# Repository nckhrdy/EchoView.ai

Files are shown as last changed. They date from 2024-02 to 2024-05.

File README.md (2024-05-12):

# EchoView.ai: AR Glasses for the Deaf and Hard of Hearing

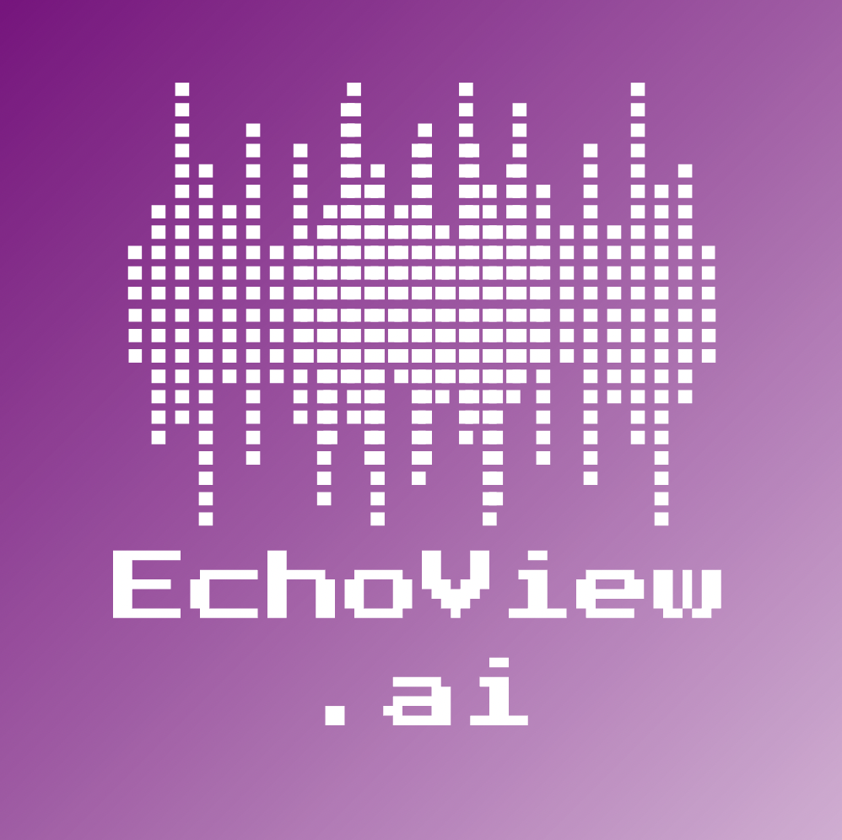
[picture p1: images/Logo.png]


## Introduction
EchoView.ai introduces an innovative solution designed to significantly enhance communication for the Deaf and Hard of Hearing community. Utilizing advanced technology, our glasses provide real-time speech-to-text transcription, displaying conversations directly in the user's field of vision.

## Mission Statement
Our mission is to foster community and innovation by enabling everyone to hold the key to understanding spoken interactions.

## Key Features
- **Real-Time Transcription:** Speech-to-text functionality that operates in real-time.
- **OLED Display:** Text is displayed on a discreet, built-in OLED screen within the glasses.
- **Bluetooth Connectivity:** Seamless integration with iOS devices through a custom app.
- **User-Friendly Design:** Lightweight, comfortable, and designed for everyday wear.

## System Overview
EchoView.ai glasses are powered by an ESP32-C3, featuring audio capturing and an OLED display for output. The system includes:
- ESP32-C3 for processing
- JVC HA-ET65BV Microphone and Device microphone, also compatible with MEMS microphones and various other audio inputs
- OLED display for text output
- Bluetooth module for mobile connectivity
- Birdbath Combiners/Optical Combiner (series of two-way mirrors) for projecting the image from OLED

## Installation
### Hardware Setup (Detailed information in README_hardware.md)
1. Connect the MEMS microphones to the ESP32-C3.
2. Attach the OLED display to the ESP32-C3.
3. Ensure all connections are secure and the system is powered (3.3v).

### Software Setup (Detailed information in README_software.md)
1. Clone this repository to your ESP32-C3.
2. Navigate to the /Device directory and flash the echoview_esp32_v1.ino file onto the ESP32.

## Usage
### Starting the Device
Power on the EchoView.ai glasses. The device will automatically boot up and the Raspberry Pi will begin processing input from the microphones.

### Using the Mobile App
1. Download the EchoView.ai app from the iOS App Store.
2. Press and hold the button on the side of the headset for 3 seconds until device flashes 3 times.
3. Navigate to Bluetooth in device Settings and connect to the headset.
4. Open the app and pair it with your EchoView.ai glasses.
5. Start Transcribing!

### Daily Operation
Simply wear the glasses as you would any regular glasses. Conversations will be transcribed in real-time and displayed in your field of view.

## Safety and Maintenance
- Keep the device dry and avoid exposure to extreme temperatures.
- Regularly update the software through the EchoView.ai app to ensure optimal performance and security.

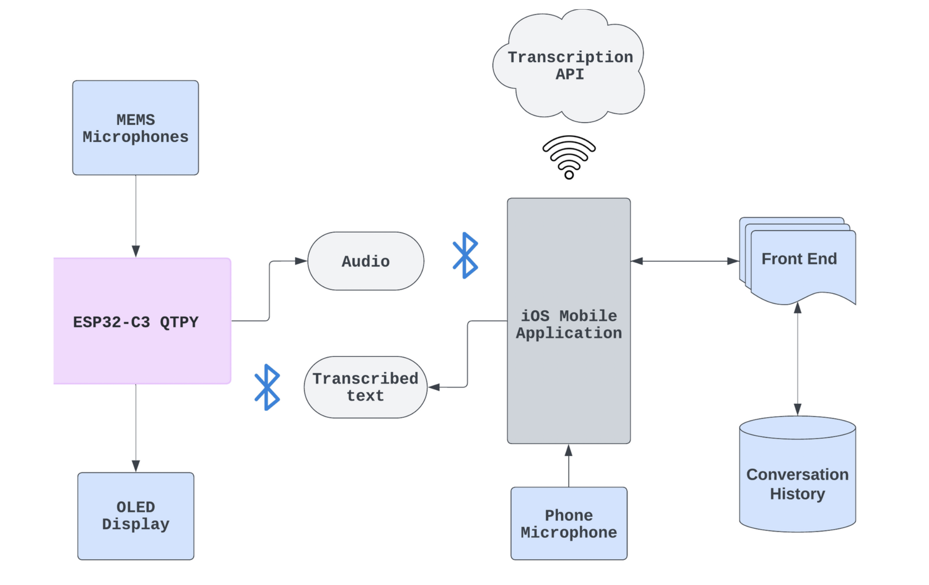
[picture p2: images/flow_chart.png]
Flow Chart


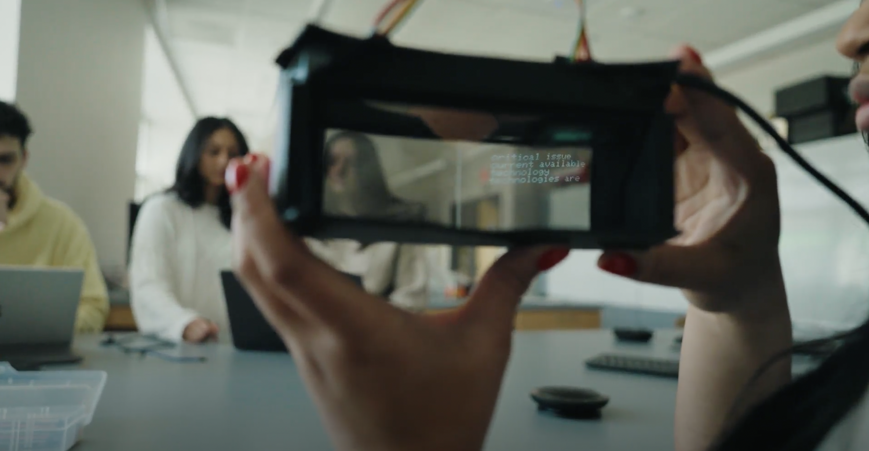
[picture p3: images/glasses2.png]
Watch the Demo (https://drive.google.com/file/d/1j2KLc6h1_2RdIPNPQ-ITHF-1azErev8u/view?usp=sharing "Watch the Demo")


For more detailed information, please refer to our [User Manual](Documentation/CopyOfPreviousReports/UserManual.pdf)

## Future Plans
EchoView.ai is exploring the integration of large language models from Hugging Face to enhance the device's capabilities. This will enable compatibility with Android devices and introduce additional languages and smart features, improving accessibility and user experience.

## Acknowledgments
Special thanks to our team members and advisors who have made significant contributions to the development and success of this project.

---
EchoView.ai – Bridging the communication gap with cutting-edge technology.

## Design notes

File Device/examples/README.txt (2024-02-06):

This bundle contains two folders, one each for the latest versions of CircuitPython. You must use the files that match the version of CircuitPython you're using, e.g. if you are using CircuitPython 7, you will copy the files from the CircuitPython 7.x folder to your CIRCUITPY drive.
To use this project bundle, simply copy the contents of the CircuitPython version folder you're using from the zip file to your CIRCUITPY drive.
Contents in each version include:
* the code.py file
* the lib/ folder and all of its contents (including subfolders and .mpy or .py files)
* any assets (such as images, sounds, etc.)
NOTE: This will replace the current code.py, and the lib folder and its contents. Back up any desired code before copying these files!
 This zip was downloaded from https://learn.adafruit.com/monochrome-oled-breakouts/python-usage-2 on February  6, 2024.

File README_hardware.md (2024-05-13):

# EchoView.ai: Hardware Report

## Overview

Our EchoView.ai device is a wearable technology enabling real-time speech-to-text transcription. This hardware report provides detailed insights into the components, schematics, and assembly required to bring EchoView.ai to life.

## Schematic and CAD Diagrams

- **System Schematic**:
<div align="center">
  
</div>

- **CAD Diagrams**:  
  - The CAD diagrams detail the physical configuration of the system's key modules.
<div align="center">
  
  <br>
  
</div>

## Bill of Materials (BOM)

### Main Components

1. **ESP32 Huzzah Feather**  
   - *Vendor*: Adafruit  
   - *Description*: An ESP32-based microcontroller board with Wi-Fi connectivity.  
   - *Link*: [ESP32 Huzzah Feather](https://www.adafruit.com/product/3405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)

2. **JVC HA-ET65BV Microphone**  
   - *Vendor*: JVC  
   - *Description*: Bluetooth-enabled, wireless sports headset with in-line microphone.
   - *Link*: [JVC Bluetooth Headset](https://www.amazon.com/JVC-Bluetooth-Headset-Wireless-Compatible/dp/B07YT8MZK4)

3. **OLED Display**  
   - *Vendor*: Adafruit  
   - *Description*: 1.3" monochrome OLED display.
   - *Link*: [Monochrome 1.3" OLED Graphic Display](https://www.electromaker.io/shop/product/monochrome-13-oled-graphic-display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)
  
4. **Lenovo Mirage Headset (Optical Combiner & Head Strap)**  
   - *Vendor*: Lenovo  
   - *Description*: Virtual reality headset used for its optical combiner and head strap.  
   - *Link*: [Lenovo Mirage Star Wars Headset](https://www.amazon.com/Star-Wars-Challenges-Lightsaber-Controller-Tracking/dp/B075C9NT67)

### Full Bill of Materials (BOM)

For a complete list of all components, including part numbers and sources, see the [BOM PDF].

## Power Requirements

- **Input Voltage**: 5V  
- **Current**: Up to 2A  
- **Power Supply Model**: Miady 5000mAh Portable Charger  
- *Link*: [Miady 5000mAh Battery Pack](https://www.amazon.com/Miady-5000mAh-Portable-Charger-Android/dp/B08T8TDS8S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)

## System Enclosure

**Material**: Grey PLA Filament  
  - *Vendor*: HATCHBOX  
  - *Description*: Durable, easy-to-print PLA filament for 3D printers, 1kg spool.  
  - *Link*: [HATCHBOX Grey PLA Filament](https://www.amazon.com/HATCHBOX-3D-Filament-Dimensional-Accuracy/dp/B015I1CYFE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)

**Lenovo Mirage Headset Components**  
  - **Optical Combiner**: Extracted from the Lenovo Mirage headset to provide optical clarity.  
  - **Head Strap**: The adjustable head strap from the Lenovo Mirage headset ensures a secure fit.  
  - *Link*: [Lenovo Mirage Star Wars Headset](https://www.amazon.com/Star-Wars-Challenges-Lightsaber-Controller-Tracking/dp/B075C9NT67)

### System Pictures

- **Angle 1**: *Insert photo here*  
- **Angle 2**: *Insert photo here*

## References and Documentation

- **Datasheets**  
  - **ESP32 Huzzah Feather**: [Datasheet PDF](https://cdn-learn.adafruit.com/downloads/pdf/adafruit-huzzah32-esp32-feather.pdf)  
  - **JVC HA-C300 Bluetooth Headset Microphone**: [Product Details at JVC](https://www.jvc.com/usa/headphones/wireless-earbuds/ha-c300/)  
  - **Monochrome 1.3" OLED Graphic Display**: [Datasheet PDF](https://www.electromaker.io/shop/download/monochrome-13-oled-graphic-display)
  - **Lenovo Mirage Headset**: [Product Overview and Specifications](https://smartsupport.lenovo.com/us/en/products/smart/arvr/jedi-challenges/solutions/pd500106-star-wars-jedi-challenges-overview)
 
- **Web Resources**  
  - **Optical Combiner**: [AltexSoft Blog](https://www.altexsoft.com/blog/augmented-reality-check-get-ready-to-ditch-your-smartphone-for-goggles/)

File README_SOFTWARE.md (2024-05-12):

# README_SOFTWARE.md

## Overview

EchoView.AI is designed to enhance communication accessibility for the deaf and hard-of-hearing community through real-time speech-to-text transcription. This comprehensive software documentation covers both the iOS application and the embedded software on the ESP32-C3, providing detailed setup, dependencies, and operational guidelines necessary for deployment and development.
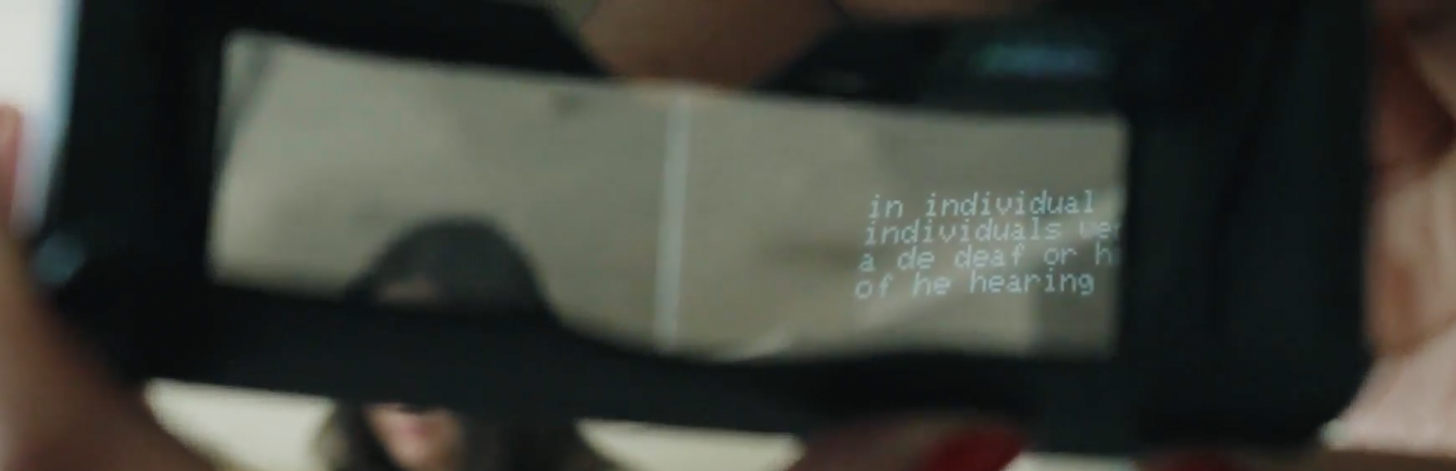
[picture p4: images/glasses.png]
Glasses


## Software Modules Overview
### **iOS Swift Application**

#### Overview
The iOS Swift application serves as the user interface for the EchoView.AI system, providing real-time speech transcription, Bluetooth management, and user settings customization. Developed using SwiftUI and Swift 5, the app leverages advanced iOS frameworks like CoreBluetooth for BLE communications and CoreData for data persistence.

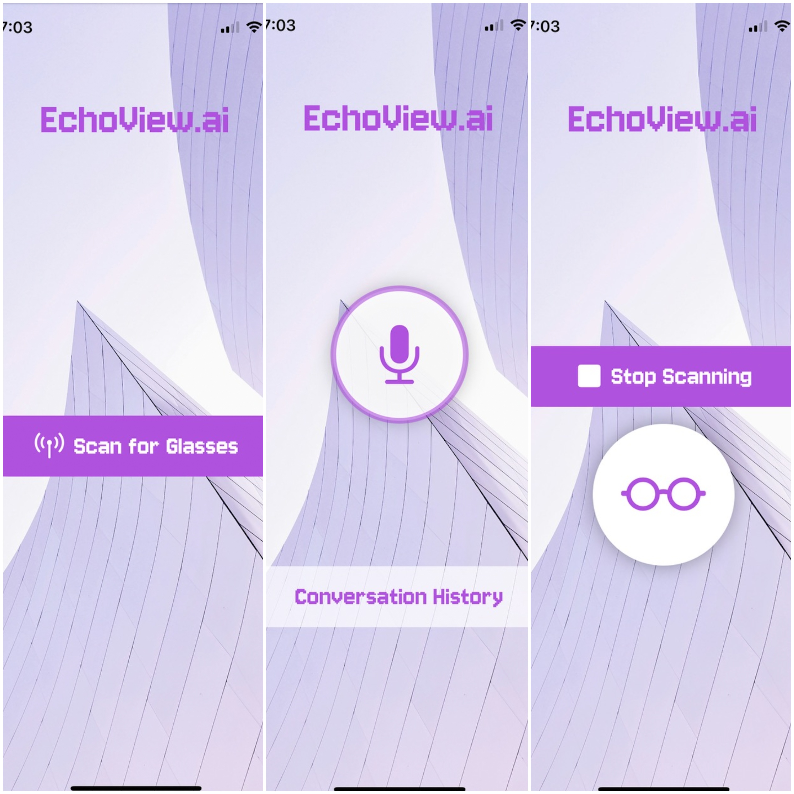
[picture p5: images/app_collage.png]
Swift App


#### Key Components
- ContentView.swift: The root view of the application, managing the main user interface elements and interactions.
- BluetoothManager.swift: Manages all Bluetooth-related operations, including scanning for devices, connecting, and data transmission.
- SpeechRecognizer.swift: Utilizes the iOS Speech framework to convert spoken language into text, managing both the audio session and speech recognition tasks.
- PersistenceController.swift: Handles all data persistence operations using CoreData, saving and retrieving transcription records.
- TranscriptionDetail.swift: Defines the data model for a transcription record, including attributes for storing date, text, and associated metadata.

#### Features
- Language/Frameworks: Developed in Swift 5 and SwiftUI for a native iOS experience.
- Main Features:
  - Bluetooth Low Energy (BLE): Manages communication with the ESP32-C3 microcontroller.
  - Transcription Display: Shows real-time transcriptions and manages transcription history.
  - Settings Customization: Allows users to customize text display settings such as size and color.

#### Operational Flow for iOS Swift Application
- Initialization:
  - Set up the main user interface.
  - Initialize core data stack for persistence.
  - Configure Bluetooth manager.
- Bluetooth Operations:
  - Scan for available BLE devices.
  - Connect to the ESP32 device.
  - Handle BLE state changes and errors.
- Transcription Management:
  - Start transcription service when user initiates.
  - Process incoming audio and convert it to text.
  - Display real-time transcription on the UI.
- Data Handling:
  - Store transcriptions in CoreData for historical access.
  - Allow users to review and manage past transcriptions.
- User Interaction:
  - Provide settings for users to customize text appearance.
  - Handle user inputs for starting/stopping transcription.
  - Navigate through different views via the navigation stack.
- Background Operations:
  - Manage app state changes (background to foreground).
  - Maintain active BLE connections and data transfer.
- Termination:
  - Properly disconnect from BLE device.
  - Save all unsaved data before app closes.
  - Clean up resources to prevent memory leaks.
---
### Embedded Software on ESP32-C3

#### Features
- Language/Platform: Implemented in C++ using the Arduino development environment.
- Main Features:
  - BLE Communication Handling: Manages BLE operations including device pairing and data transmission.
  - Audio Input Management: Captures and processes audio input from MEMS microphones.
  - Data Processing: Converts audio signals into formatted text to be sent back to the iOS application.

#### Overview
The firmware for the ESP32 microcontroller manages the Bluetooth Low Energy (BLE) communications and the OLED display to show text received from the iOS application. It is developed using the Arduino platform and utilizes the Adafruit_GFX and Adafruit_SSD1306 libraries for display operations and the BLEDevice library for BLE functionality.

#### Key Components
- echoview_esp32_v1.ino: This is the main file of the ESP32 firmware. It includes the setup and loop functions where the BLE server is configured, and the OLED display is managed.

#### Details
- BLE Setup: The firmware initializes a BLE server, advertises services, and handles connections and disconnections. It defines custom service and characteristic UUIDs to facilitate communication with the iOS application.
- OLED Display Management: Using the Adafruit_SSD1306 library, the firmware controls an OLED display to show text messages received over BLE. The text display supports basic scrolling when messages exceed the display area.
- Data Handling: Implements a callback mechanism to receive and process text data sent from the connected BLE device. The text is then displayed on the OLED screen and optionally echoed back to confirm receipt.

#### Functions
- addText(String text): Adds text to the display, managing line breaks and scrolling.
- MyServerCallbacks: Handles events for BLE server connections and disconnections.
- MyCallbacks: Processes write operations on the BLE characteristic, updating the display with received text.

#### Operational Flow
- Initialization:
  - Start Serial communication.
  - Initialize BLE server and services.
  - Set up OLED display.
- BLE Operations:
  - Advertise BLE service and characteristics.
  - Handle BLE connections and disconnections.
  - React to data written to input characteristics.
- Display Management:
  - Receive text via BLE.
  - Check if new text exceeds the display area.
  - Scroll display if necessary or append new text.
  - Update OLED display to show new text.
- Continuous Operation:
  - Maintain BLE availability.
  - Keep listening for incoming BLE connections and data.
  - Refresh OLED display based on received data.
- Handling Disconnections:
  - Automatically restart advertising to allow reconnection.
  - Clear display or display a status message.
---
### **OLED Display Management**

#### Overview
The OLED display management is implemented using a Python script running on a device equipped with an I2C interface, such as an ESP32 or Raspberry Pi. This script uses the Adafruit_SSD1306 library to control an OLED display and display text data dynamically. It is designed to handle streaming output from a subprocess, which can be customized for various use cases such as displaying real-time speech to text transcriptions.

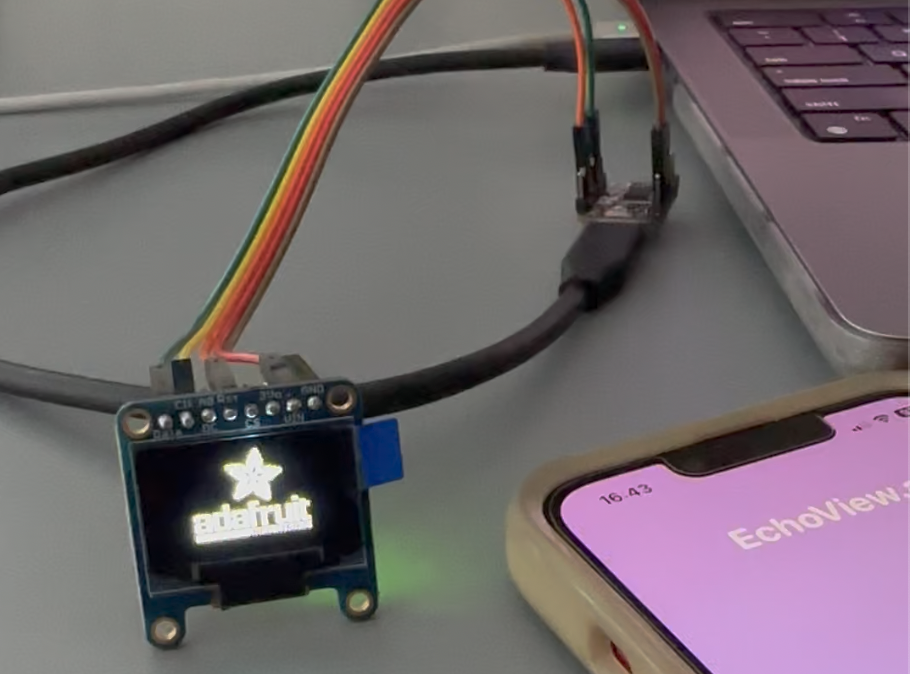
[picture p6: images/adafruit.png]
Adafruit

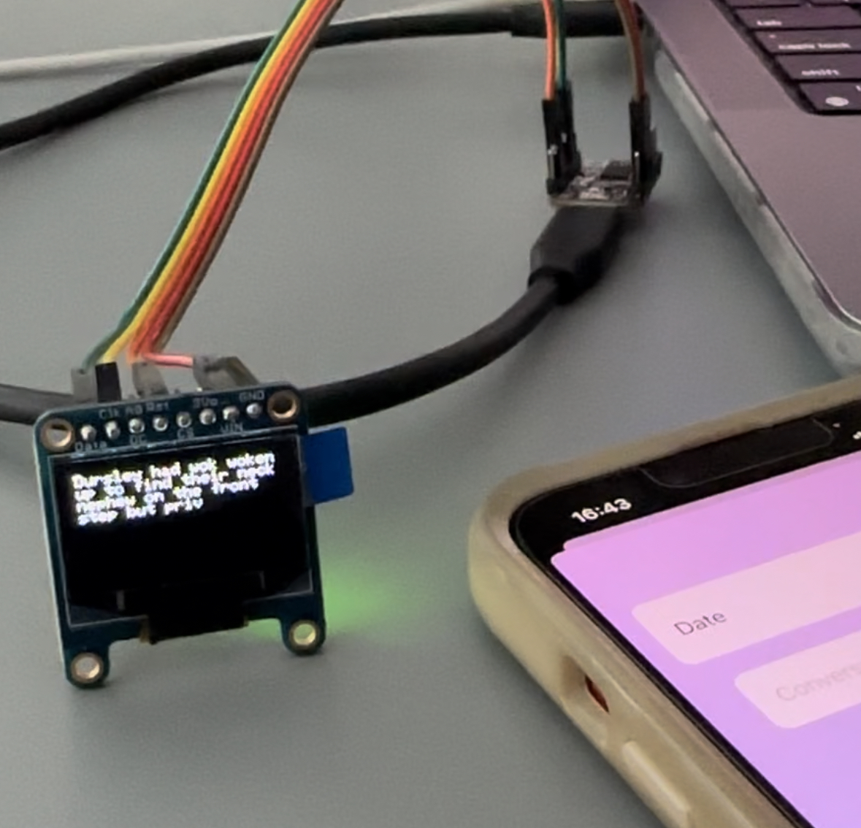
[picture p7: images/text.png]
Text


#### Key Components
- echoviewai_v.0.1.py: The main Python script that initializes the OLED display, processes incoming text, and updates the display in real-time.

#### Details
- Initialization: Sets up the I2C interface and initializes the OLED display using specific dimensions and address.
- Text Display Management: Uses the Python Imaging Library (PIL) to create an image buffer where text is drawn. The script wraps text to fit the OLED display's width and updates the display with new text as it arrives.
- Subprocess Management: Starts a subprocess that is intended to continuously provide output text, which is read line by line and displayed on the OLED.

#### Functions
- update_display(text): A function that clears the current display, wraps the incoming text based on the display's width, and updates the OLED screen to show the new text.

#### Operational Flow
The following flow chart illustrates the operational logic from subprocess initiation to display updating:
- Initialization:
  - Initialize I2C interface.
  - Set up OLED display with Adafruit_SSD1306.
- Script Execution:
  - Start a subprocess to stream output.
- Display Update Process:
  - Read output from the subprocess line by line.
  - Clear display.
  - Wrap text to fit display width.
  - Update display with new text.
- Continual Update:
  - Loop through the subprocess output.
  - Handle each line of text in real-time.
  - Refresh the OLED display with each new line.
- End Process:
  - Close subprocess.
  - Clear display on script termination.

## Flow Chart
The following flow chart illustrates the interaction between the iOS application, the ESP32-C3 microcontroller, and the OLED Display:

System Interaction Flow Chart

## Dependencies and Build Tools

### iOS Application
- **Xcode 12 or later**: Essential for iOS app development.
- **Swift 5**: Programming language.
- **CocoaPods**: Dependency manager used to install and manage third-party libraries.
  - **CocoaPods Libraries**: List specific libraries and versions.
  
### ESP32-C3 Software
- **Arduino IDE**: Used for developing and uploading C++ code to the ESP32.
- **ESP32 Board Definitions**: Must be added to the Arduino IDE for ESP32 support.
- **Adafruit SSD1306 Library**: For OLED display operations.
- **Additional Libraries**: Specify other libraries and their versions.

## Setup and Installation Instructions

### iOS Application Setup
1. **Clone the repository:**
   ```bash
   git clone https://github.com/nckhrdy/EchoView.ai.git
   ```
2. **Install dependencies:**
   ```bash
   cd EchoView.ai/App/ios
   pod install
   ```
3. **Open the .xcworkspace file in Xcode:**
   ```bash
   cd EchoView.ai.xcworkspace
   cd project.xcworkspace
   ```
4. **Build and run the application on a compatible iOS device.**

### ESP32-C3 Firmware Setup
1. **Install the Arduino IDE and ESP32 Board definitions.**
2. **Go into Folder where the firmware / ESP32 software is located:**
   ```bash
   cd Device
   ```
3. **Open the file (echoview_esp32_v1.ino) in Arduino IDE**
4. **Connect the ESP32-C3 via USB and select the correct port in Arduino IDE.**
5. **Compile and upload the software to the ESP32-C3**

## Build and Deployment

### iOS Application
- Use Xcode to build and deploy the application on an iOS device
- Ensure the device's Bluetooth is turned on and pair it with ESP32-C3

### ESP32-C3
- The ESP32-C3 auto-starts the software upon boot
- Make sure it is powered and in range of the iOS device for initial BLE pairing
- Compile the firmware in the Arduino IDE.
- Use the 'Upload' button to flash the compiled binary directly to the connected ESP32 device

## Hardware and Software Interface

### Bluetooth Interface
- Manages connectivity between the iOS device and ESP32-C3

### Audio Data Management
- Real-time audio data capture and processing on ESP32-C3

## Future Developments

### Cross-Platform Compatibility and Language Support

As EchoView.AI evolves, we plan to enhance its accessibility and functionality by leveraging Hugging Face's Large Language Models (LLMs). These advancements are aimed at making the application compatible across both Android and iOS platforms, thereby reaching a broader user base. By integrating LLMs, we expect to introduce a variety of smart features, including:

- **Multilingual Support**: Expanding the application's language capabilities to include multiple languages, which will allow users from different linguistic backgrounds to benefit from our service.
- **Enhanced Contextual Understanding**: Utilizing the advanced natural language processing (NLP) capabilities of LLMs to improve the transcription accuracy and context awareness of the speech-to-text engine.
- **Smart Interaction Features**: Developing features that enable more interactive and responsive communication aids, such as real-time suggestions and automated responses based on the context of the conversation.

### Integration Goals

- **Android Compatibility**: Adapt the existing iOS-based application to also function seamlessly on Android devices, ensuring a uniform user experience across different mobile platforms.
- **User Interface Adaptation**: Redesign the user interface to accommodate additional features while maintaining ease of use and accessibility.

These future developments are intended to not only extend the reach of EchoView.AI but also to enhance the overall user experience by incorporating cutting-edge AI technologies. Our goal is to create a universally accessible tool that aids communication for the deaf and hard-of-hearing community in a variety of scenarios and languages.

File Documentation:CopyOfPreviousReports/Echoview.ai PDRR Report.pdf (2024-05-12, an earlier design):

EC463 – 2023 PDRR REPORT | 1

# EchoView.ai: Augmented Reality Glasses with Real-Time Speech-to-Text Capability

Hassan Hijazi, Riya Deokar, Nicholas Hardy, Jazmyn Walker, Marybel Boujaoude

Abstract— The development of Augmented Reality glasses equipped with real-time transcription capabilities will introduce groundbreaking innovation within the field of assistive technology and assist in bridging the gap between the Deaf and hearing community. By seamlessly converting spoken language into text in real time, this technology will empower hard of hearing and Deaf individuals to engage fully with the hearing-centric world. This device will include speech recognition software and a built-in display system that projects text into the user’s field of vision. Additionally, a mobile application will store transcription history, allowing users to revisit and reference past conversations. With a user-friendly interface and simple compatibility with mobile devices, these AR glasses will break down communication barriers and create a more inclusive society.

Index Terms—Artificial, augmented, and virtual realities, User Interfaces, Natural Language Processing, Speech recognition and synthesis, Assistive technologies for persons with disabilities, Affective computing applications, Education, Health care

—————————— ◆ ——————————

### 1 NEED FOR THIS PROJECT

or the Deaf and hard of hearing community, seamless communication in a largely hearing world can be complicated and in some cases impossible. Despite continuous advancements in assistive technology, a significant gap persists in providing real-time, accessible, affordable, and convenient solutions. Approximately 1.5 billion individuals globally are currently affected by hearing loss in one or both ears, with an estimated 430 million people worldwide requiring rehabilitation for severe hearing loss. This number is expected to increase to 700 million people being affected by hearing loss by 2050 [1]. The effects of this communication gap are profound and have damaging consequences. Deaf and hard of hearing individuals often find themselves isolated from spoken conversations and missing out on everyday interactions. While current solutions exist, they are costly, lack immediate access, and are overall ill-suited for fast-paced real-world environments. Sign language interpreters can cost up to $150 per hour, not including additional travel costs, and often take prior planning to schedule [2]. Given these challenges, there is a clear and urgent need for an improved solution. The Global Assistive Technology Market was valued at 21.95 billion U.S. dollars in 2022 and is projected to reach a value of 31.22 billion U.S. dollars by 2030 [3]. More specifically, the domestic market for AR headsets and glasses was valued at 2.4 billion U.S. dollars [4], and 31.12 billion dollars globally in 2023. AR and VR is a growing market with an expected growth of +366.91 percent by 2027, so entering this market with a more affordable option could accelerate the adoption of AR/VR and grant Echoview.ai a large share of the consumer market. Our proposed Augmented Reality (AR) glasses, with real-time speech-to-text capabilities and a mobile application, aim to address the communication barriers faced by the Deaf and hard of hearing community. Through a business-to-business (B2B) and business-to-consumer (B2C) model, we will introduce these Augmented Reality (AR) glasses to consumers that will benefit from improved accessibility at an affordable cost. Hospitals can have clearer communication between patients and staff, educational centers can integrate these glasses into their classrooms to promote an inclusive learning environment, and courtrooms can be sure that legal proceedings are accessible to all participants. Our device will enhance personal interactions, foster inclusivity, and provide a more cost-effective solution to existing assistive technologies.

### 2 PROBLEM STATEMENT & DELIVERABLES

### 2.1 Problem Statement

The Deaf and hard of hearing community has continuously faced several challenges in a world where the main form of communication is using spoken language. While alternative assistive technologies exist, they are very expensive, and often fall short of providing real-time, accessible solutions to communication barriers. Standard methods such as the reliance on sign language interpreters and conventional speech-to-text solutions can be costly, require prior planning, and limited in availability. Our proposed solution seeks to address this issue by developing Augmented Reality (AR) glasses equipped with real-time speech-to-text capabilities. By processing spoken language and displaying it as readable text, we aim to bridge the communication gap and allow users to easily interact in various environments including hospitals, educational institutions, court rooms, and more. Our design will feature a sleek and comfortable wearable device that is equipped with a high-
quality | microphone | array, | allowing | for | accurate
transcription in loud or crowded environments. Intended for extended use, our glasses will provide up to 2 hours of

EC463 – 2023 PDRR REPORT

————————————————
- Hassan Hijazi CE’24. E-mail: hhijazi@bu.edu
- Riya Deokar CE’24. E-mail: riyaa@bu.edu
- Nicholas Hardy CE’24. E-mail: nckhrdy@bu.edu
- Jazmyn Walker CE’24. E-mail: jazmynw@bu.edu
- Marybel Boujaoude CE’24. E-mail: marybelb@bu.edu

F

2 | EC463 – 2023 PDRR REPORT

battery life, making them ideal for daily wear. We will
develop an accompanying mobile application with a user-friendly interface that will store previous transcriptions allowing the user to revisit past conversations. It will also provide options for customization of text size, font, and display preferences. Our device will create a more inclusive world that transforms how the Deaf and hard of hearing community is able to communicate by offering an immediate and accessible solution.

### 2.2 Deliverables

Augmented Reality glasses capable of:
1. Real-time speech-to-text transcription
2. Projecting transcribed text into user’s field of vision
3. Providing a long-lasting battery life (2-3 hours)
4. Offering comfortable wear with an ergonomic design
5. Wireless pairing with a mobile application for enhanced control
A mobile application capable of:
1. Seamlessly pairing with the AR glasses
2. Storing transcription to allow users to reference previous conversations
3. Offering a user-friendly interface, enabling effortless control over the settings of the AR glasses
4. Ensuring compatibility with popular platforms (iOS and Android)

### 3 VISUALIZATION

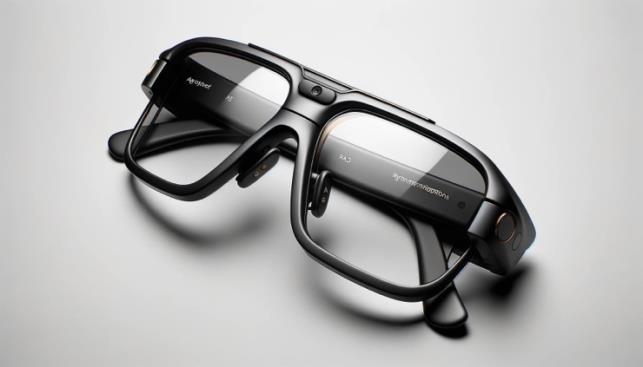
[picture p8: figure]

Fig. 1. This is a representation of our final product design. The glasses will be engineered to offer real-time speech-to-text capabilities while integrating a sleek and sophisticated design to optimize comfort and style.

Fig. 2. This diagram offers a comprehensive schematic of our Echoview.ai glasses. Audio input is captured through a microphone array and an OLED display will provide real-time visual feedback to the user. For off-device communication, a microcontroller will interface with a cell phone via a Bluetooth connection. The device will also work using WiFi or LTE granting the system access to cloud resources and services. The mobile app provides a simple user interface for customization and further interaction with the device. Overall, this diagram displays how we will seamlessly integrate hardware and software components to create Augmented Reality (AR) glasses.

### 4 COMPETING TECHNOLOGIES

With the rapidly increasing need for assistive technologies, the emergence of competing ventures has grown. There are several competing AR glasses currently on the market from companies such as Google, XRAI, TranscribeGlass, and Xander.

### 4.1 Google Translation Glass

Google has begun development of augmented reality glasses that are capable of live transcription and live translation. The glasses also feature a camera which can interpret sign language and output the text on the lens in real time. The product is still in development, and there is no timetable for their release, or expected price.

### 4.2 XRAI Glass

XRAI Glass is an app developed to provide real time transcription and translation when paired with AR glasses which start at 379.99$. The application has a free version which limits the user to only transcription and one day chat history, or more costly monthly subscriptions which allow for translation and AI assistant technology. The monthly subscription cost is 19.99 for the premium version, and 49.99 for the ultimate version.

### 4.3 Transcribe Glass

Similar to our project, TranscribeGlass provides real-time subtitles using speech-to-text recognition, addressing the need for immediate transcription. It has an ease of an attachment, because it can be attached to any existing eyeglass, making it a convenient and cost-effective option for those who already wear glasses. Users can integrate their preferred speech-to-text recognition software, adjust font size, select languages, and store transcriptions, offering a personalized experience. Additionally, there is day-long battery life on a single charge.

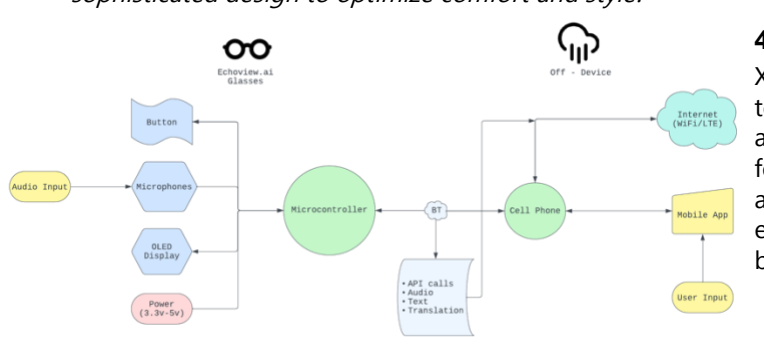
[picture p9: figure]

### 4.4 Xander Glass by Vuzix

Xander glass offers real-time captions through speech-to-text technology. They excel in user friendliness by easily attaching to existing glassware. Customizability is a key feature, allowing users to tailor font size, choose languages, and store transcriptions, delivering a personalized user experience. Furthermore, Xander glasses have a day-long battery life on a single charge.

HASSAN HIJAZI, RIYA DEOKAR, NICHOLAS HARDY, JAZMYN WALKER, MARYBEL BOUJAOUDE: ECHOVIEW.AI | 3

### 5 ENGINEERING REQUIREMENTS

This section describes the engineering requirements based on the specific subsection.

### 5.1 Hardware & Mechanics

1. Must be designed for comfortable wear made for extended periods of time of up to 4 hours.
2. Glasses must not exceed a weight of 300 grams to ensure comfort and keep up with competitors [5].

### 5.2 Speech-to-Text Processing

1. The AR glasses ust incorporate real-time speech-to-text processing capabilities with a target response time of 10 milliseconds for local processing, allowing users to view captions as conversations unfold.
2. Noise Specification – The device will work in environments with noise levels of up to 90 dBA. We must specify the ambient noise conditions for the system accurately, considering both local and remote processing scenarios, and explore the potential use of phone apps to estimate background noise levels (measured in dBAs).

### 5.3 Mobile Application

1. The application must be compatible with both iOS and Android platforms.
2. The system must maintain a stable connection to WiFi and LTE, ensuring access to cloud services.

### 5.4 Power & Cost

1. The AR glasses must remain operating for 2-3 hours on a single charge.
2. The total component cost should not exceed more than $500 to ensure a competitive market price.

ACKNOWLEDGMENT

The authors wish to thank Professor Alan Pisano, Professor Osama Alshkh, Professor Michael Hirsch, and Professor Thomas Little for their continuous support throughout the project.

REFERENCES

[1] J. Wirth, A. Hall, and L. Jorgenson, “Deafness and hearing loss
statistics,” | Forbes, | https://www.forbes.com/health/hearing-
aids/deafnessstatistics/#:~:text=Approximately%2010.7%20million%20people %20ages,U.S.%20have%20profound%20hearing%20loss [accessed Oct. 12, 2023].
[2] “How to pay for Translation Services,” Monitor on Psychology, https://www.apa.org/monitor/2020/01/career-other-wordssidebar.html [accessed Oct. 12, 2023].
[3] “Assistive Technology Market - Global Industry Assessment &
Forecast,” | Vantage | Market | Research,
https://www.vantagemarketresearch.com/industryreport/assistive-technology-market-1786 [accessed Oct. 12, 2023].
[4] T. Alsop, “Topic: AR headsets and Glasses,” Statista, https://www.statista.com/topics/10134/ar-glasses/#topicOverview [accessed Oct. 10, 2023].
[5] T. Alsop, “AR headsets and glasses comparison by weight 2023,” Statista, https://www.statista.com/statistics/1337293/ar-glassescomparison-by-weight/ [accessed Oct. 12, 2023].

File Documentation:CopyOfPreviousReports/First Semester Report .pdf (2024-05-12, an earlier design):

First Semester Report Draft

Team 3: EchoView.AI

Hassan Hijazi CE’24. E-mail: hhijazi@bu.edu Riya Deokar CE’24. E-mail: riyaa@bu.edu Nicholas Hardy CE’24. E-mail: nckhrdy@bu.edu Jazmyn Walker CE’24 E-mail: jazmynw@bu.edu Marybel Boujaoude CE’24. E-mail: marybelb@bu.edu

Table of Contents
Executive Summary | 2
1.0 | Introduction | 2
2.0 | Concept Development | 3
3.0 | System Description | 4
4.0 | First Semester Progress | 5
5.0 | Technical Plan | 6
6.0 | Budget Estimate | 7
7.0 | Attachments | 7
7.1 | Appendix 1 – Engineering Requirements | 7
7.2 | Appendix 2 – Gantt Chart | 8
7.3 | Appendix 3 – Other Appendices | 8

Executive Summary

The need for accessible, cost-effective, and immediate communication tools for the deaf and hard-of-hearing community is critical and urgent. Current available technologies are costly, complex, and unable to be seamlessly integrated into daily life. Our solution is to introduce a revolutionary wearable device: glasses that provide real-time speech-to-text transcription. By integrating advanced technology into a discrete, everyday accessory, we will be reducing communication barriers faced by individuals who are deaf or hard of hearing. The final deliverable is a pair of assistive glasses, equipped with an OLED display that will display transcribed text into the user’s field of vision, a Teensy 4.1 microcontroller for processing, an ESP32-C3 for wireless communication, and a microphone for audio capture. Additionally, we will develop an iOS-compatible mobile application that enables the user to reference past conversations and customize the displayed text based on their preferences. Our technical approach leverages open-source speech recognition software with microcontroller technology, ensuring accurate transcription. Innovative features of our design include low power consumption, a customizable display, and adaptability since it utilizes open-source software that is enhanced by continuous, community-driven developments. Our end product delivers a new way for deaf and hard-of-hearing individuals to communicate, cultivating a more inclusive world where every voice and word can be heard and understood.

### 1.0 Introduction

Deaf and hard-of-hearing individuals face significant challenges in their daily lives when they wish to communicate with others. These challenges lead to social isolation and limited access to information, adversely affecting their quality of life. Current assistive technologies often fall short of addressing these issues comprehensively. These shortcomings, as well as the gravity of their challenges, underscore the critical need for innovative assistive technologies. While existing solutions often fail to provide a comprehensive solution, our project aims to bridge this gap by designing and building affordable smart glasses from scratch. These glasses will combine cutting-edge technology with affordability, empowering individuals with hearing difficulties to engage fully in conversations and access information effortlessly with added smartphone components. Designing our glasses from the ground up gives us the flexibility to incorporate microphone arrays and speech-to-text processing technologies that work well together. This enables our real-time transcription of spoken language to be highly accurate, ensuring that users can understand and participate in conversations. These glasses will also offer an ergonomic and customizable design, to prioritize user comfort and accessibility. Our user-friendly interface will allow individuals to personalize settings to ensure optimal readability. The end goal is for out glasses to seamlessly pair with a dedicated mobile application so that users can better control and store transcription and translation records. We are also actively exploring the integration of multi-language translation capabilities, which would render our product indispensable for other populations. With a focus on affordability, we are committed to making these glasses accessible to a wider audience. Our project is distinguished by several key highlights: affordability, accuracy, and ergonomics.

### 2.0 Concept Development

The core problem for our customers who are deaf or hard-of-hearing is the inability to access auditory information in real-time, which creates a communication barrier and hinders their interactions throughout their daily lives. The solution to this problem is to engineer a device that captures spoken words, processes them into text accurately, and presents the transcription in a readily accessible format. This requires a system that is portable, discreet, comfortable, and capable of operating in real-time with high accuracy under various environmental conditions. First of all, the system must be able to process audio in real-time. To do so, it must capture sound effectively via a microphone and then convert this audio data into text format accurately, and with minimal delay. Secondly, the device must be able to work in a variety of settings, ranging from quiet rooms to noisy outdoor areas. It therefore requires advanced noise-cancellation and speech recognition algorithms capable of adapting to different conditions. Similarly, the user interface and display are critical components. The transcribed text must be visible and presented in an easily readable manner. We must consider the display’s size, lighting conditions, and any potential pre-existing visual impairments of the user. Additionally, it must be portable and wearable. The device should be lightweight so it does not slip off the user’s face and must be comfortable for daily use. We will also consider power efficiency as the user will most likely want to wear the device for a long period. Therefore our product must be designed to minimize energy consumption and reduce the frequency of recharging. To combat these challenges, we have chosen to develop glasses, integrated with an OLED display for real-time speech-to-text transcription. We chose glasses because they are a daily accessory that many people already wear which will make the device practical and discrete. The OLED will ensure that users can read the transcribed text even when looking at others, so that they can communicate naturally.. Through an iOS mobile application, we will also include the option to customize the text being displayed, including the size, brightness, and font. We will also incorporate a Teensy 4.1 microcontroller and an ESP32-C3 module that will allow for sophisticated audio processing and wireless communication. This will enable efficient and accurate real-time transcription. Finally, a microphone is necessary to capture audio to send to the microcontroller. Overall, this approach addresses the core engineering challenges, and offers a practical, user-friendly, and innovative solution.

### 3.0 System Description

The EchoView.ai glasses will transcribe speech onto a pass through display in real time. The glasses will be designed to minimize costs while maximizing the computational abilities. The product itself fits together multiple components into a lightweight, unobtrusive and fashionable device. The glasses main microcontroller is the Teensy 4.1 (or maybe Rpi 2w) paired with an ESP32-C3. We chose the Teensy 4.1 because of its optimal power efficiency and the number of I2C ports, as well as its 7 UART communication pins. The Teensy 4.1 allows us the flexibility to build on top of existing Open-Source libraries. Since the Teensy 4.1 does not have any Bluetooth or WiFi capabilities, we are using the RX/TX pins to communicate with the ESP32-C3. We selected this model of ESP32 because of its exceptionally small form factor as well as its BLE and WiFi capabilities.
With both the ESP32-C3 and the Teensy 4.1 tied together with the microphones and powered by a 3v battery, the audio will be compressed and sent wirelessly to a mobile application running on the user’s device. Once the wireless connection is established, the audio channels will constantly report to the mobile app and compute the live transcriptions using Apple's Siri frameworks. This allows for faster computation times as we are using a native transcribing tool on the device, as well as utilizing the faster processors from the mobile device. Finally, once the transcription has occurred using Apple's frameworks, the text will be wirelessly transmitted back to the glasses via BLE connection, and displayed on the translucent OLED display over an I2C connection.

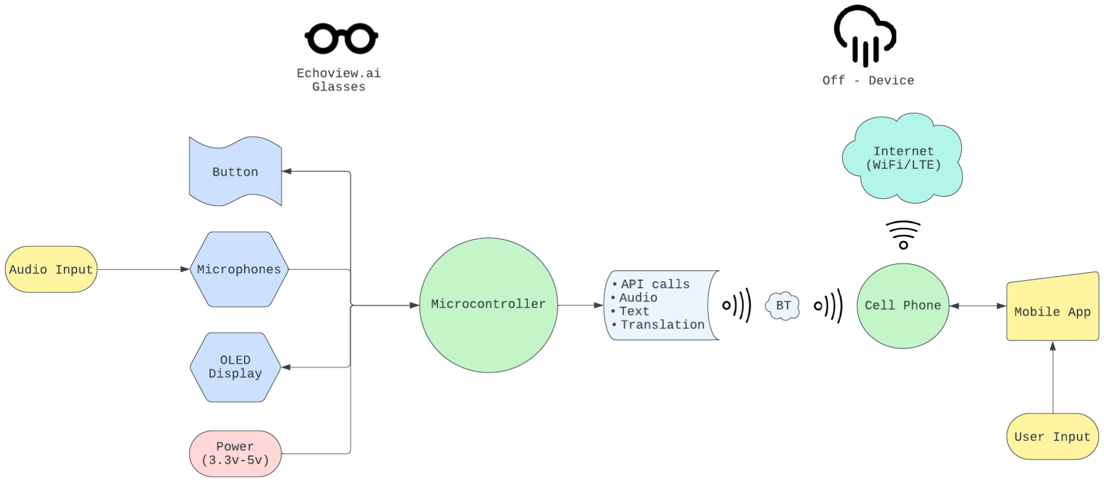
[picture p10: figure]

Fig. 1

### 4.0 First Semester Progress

In the first semester of our EchoView.AI project, we aimed to create affordable glasses from scratch while maintaining functionality. We made substantial technical progress by sourcing hardware, designing custom glasses components, and exploring AI-driven speech transcription.

4.1 Project Milestones and Goals
In the first semester of our project, Team 3 – EchoView.AI set out to achieve several key milestones and goals. Our primary objective was to develop affordable glasses from scratch, emphasizing cost-effectiveness without compromising on functionality.

4.2 Technical Achievements
During this semester, we made technical progress in the development of our glasses. We successfully obtained the hardware components from the microcenter, focusing on affordability and performance. Our technical achievements include:
- Beginning design and fabrication of custom glasses hardware
- Development of a prototype battery power supply with a focus on reusability and weight optimization.
- Initial design and testing of the optical display components, including OLED screens.
- Exploratory research into AI-driven speech transcription and translation for real-time communication.
- Coding of Swift app development for speech-to-text capabilities, a crucial component of our glasses.
- Integrated the innovative translucent OLED display and Teensy microcontroller and completed the pinout configuration and wiring
- Through comprehensive testing and validation, we confirmed that our system can effectively provide accurate transcriptions achieving an average accuracy rate of 95.4% in ideal noisy conditions and 99.4% in a quiet room.

4.3 Goals for Future Development
While our team has made significant progress in various aspects of the project during this semester, there are still key goals we aim to achieve in the upcoming phases of development. These goals include:
- Conducting comprehensive testing of the glasses in various indoor and potentially noisy environments to ensure reliability and functionality in real-world scenarios.
- Implementing advanced features, such as the ability to respond to transcribed conversations, as part of our stretch goals.
- Exploring and integrating AI-driven language processing capabilities to improve the accuracy of transcription and translation, including handling idiomatic expressions.
- Further refining the Swift app development for seamless speech-to-text functionality, ensuring it meets the needs of our target users.

- Continuously optimizing power management techniques to achieve our goal of at least 4 hours of battery life.
- Conducting detailed load-time testing for transcription/translation computations performed on and off the device to determine efficiency and responsiveness.
- Staying updated with developments in competing technologies and incorporating valuable insights into our project.

4.4 Non-Technical Progress
In parallel with our technical efforts, we have also made non-technical progress. This includes refining our project management approach, identifying key stakeholders, and initiating discussions with potential advisors.

### 5.0 Technical Plan

Task 1: Transparent OLED Display Selection
Select and procure transparent OLED displays for integration into the glasses. OLED displays should meet specifications for size, resolution, and anti-reflectivity. Compatibility with the chosen microcontroller should also be ensured. The deliverable is a set of transparent OLED displays meeting the project's technical requirements.

Task 2: Microphone Procurement
Procure high-quality microphones suitable for speech recognition and transcription. Microphones should meet sensitivity, noise reduction, and compatibility specifications with the chosen microcontroller. The deliverable is high-quality microphones that adhere to project specifications.

Task 3: Battery Power Supply Design
Design and fabricate a battery power supply system for the glasses. The system should support recharging via an external connector, meet weight limitations, and manage heat dissipation effectively. Test the design using a dummy load of 900 ohms. The deliverable is a functional battery power supply system with the ability to recharge and meet all technical specifications.

Task 4: Transparent Lens Procurement
Procure transparent lenses suitable for the glasses. Lenses should meet specifications for magnification and compatibility with the OLED displays. Considering StickTite Lens products for magnification. The deliverable is transparent lenses that fit the glasses and provide the desired magnification.

Task 5: Testing Framework Development
Develop an emulator framework for testing the glasses' functionality. Ensure the framework can simulate various scenarios, including real-world conditions and conversations. The deliverable is a functional testing framework for glasses with the ability to simulate different usage scenarios.

### 6.0 Budget Estimate

Item | Description | Cost
1 | StickTite Bifocal Lenses 2.0x Magnification | $39.98
2 | StickTite Bifocal Lenses 3.0x Magnification | $39.98
3 | Transparent OLEDs’ | $71.97
1 | Sandisk 64GB | $19.99
1 | Teensy 4.1 Development Board | $31.99
3 | Adafruit ESP32 | $29.97
| Total Cost | $151.93

### 7.0 Attachments

### 7.1 Appendix 1 – Engineering Requirements

Team # 3 | Team Name: EchoView.AI
Requirement | Value, range, tolerance, units
Weight | <300 grams
Response Time | ~10 ms
Noise Specification | Work with noise levels of up to 90 dBA
Compatibility | iOS compatibility
Connection | Connects to WiFi and LTE
Battery Life | 2-3 hours operation time
Cost | <$300
Durability | Must withstand drops from 1.5 meters
Audio Input range | 2 meters distance from source
Customization | Adjustable text size and contrast on display

### 7.2 Appendix 2 – Gantt Chart

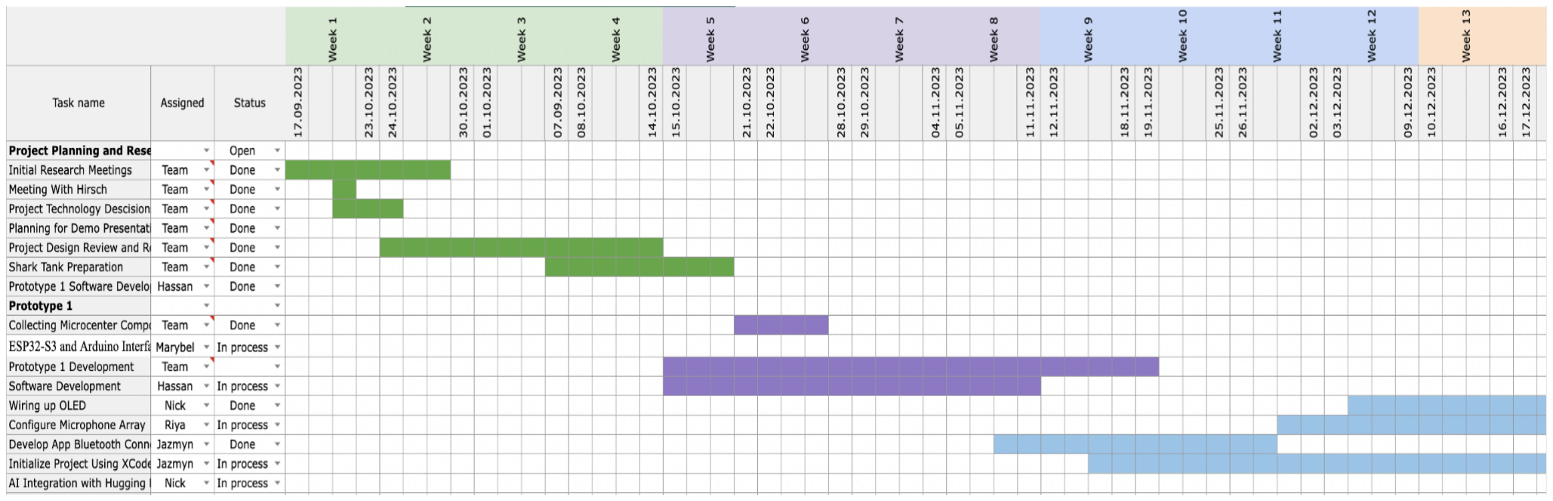
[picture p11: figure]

### 7.3 Appendix 3 – Other Appendices

Other typical attachments that are added to bolster the competitiveness of your proposal:

- Technical references (in proper bibliographic form) including key URLs.
- Your drawings and schematics (rather than embedding in text)
- Team information sheet (Biographical paragraph on each member; phone numbers and e-mail, history of team and company)

– Nick Hardy (Microphone Array Configuration and Transparent OLED Display Lead): Nick Hardy leads the configuration of the directional microphone array, ensuring it effectively cancels noise and synchronizes seamlessly with the microcontroller output. Additionally, Nick takes charge of sourcing a suitable OLED display for integration, testing readability in various lighting conditions, and working on a magnification solution. His dual role ensures that both the microphone array and OLED display meet the project's requirements.
CE’24, e-mail: nckhrdy@bu.edu, phone number: 617-610-0539

– Hassan Hijazi (Xcode/Swift/Backend Code and Testing Lead):
Hassan Hijazi is responsible for the Xcode, Swift, and backend code development. He initiates the iOS app project using Xcode, designs the app architecture, and builds user interface components for the app's backend functionality. Hassan's expertise ensures the smooth operation of the app and its seamless integration with the hardware. In addition to his app development role, Hassan played a crucial part in the testing phase. He was the lead for conducting thorough tests in both quiet and noisy rooms to assess the performance of the real-time transcription capabilities.
CE’24, e-mail: hhijazi@bu.edu, phone number: 224-283-2675

– Jazmyn Walker (App Development Frontend Lead):
Jazmyn Walker leads the frontend development of the app, focusing on creating a user-friendly and accessible interface using IOS frameworks. Her role involves designing and building user interface components. Jazmyn's work ensures that the app provides real-time transcription capabilities. Jazmyn's technical proficiency extends to leveraging iOS frameworks for live transcription. This involves implementing advanced algorithms and speech-to-text libraries to achieve real-time transcription accuracy. Her knowledge of Swift, coupled with the power of iOS frameworks, ensures that the app operates efficiently while delivering high-quality transcription results.
CE’24, e-mail: jazmynw@bu.edu, phone number: 585-709-1460

– Marybel Boujaoude (Microcontroller Interface and Glasses Manufacturing Lead):
Marybel Boujaoude plays a pivotal role within the team, taking on responsibilities in two critical areas. As the Microcontroller Interface Lead, she is responsible for programming both the ESP32-S3 and Arduino Teensy microcontrollers, ensuring seamless real-time data processing. Her role involves guaranteeing connectivity between the microcontrollers and the various hardware components, such as the OLED display and microphone array. Collaborating closely with Nick on data reception, Marybel ensures that data flows efficiently and accurately within the system.
CE’24, e-mail: marybelb@bu.edu, phone number: 603-952-8495

– Riya Deokar (Machine Learning Integration Lead):
Riya Deokar continues her role as the Machine Learning Integration Lead, focusing on researching and selecting speech-to-text libraries from Hugging Face. She actively plans the integration of AI models with both the mobile app and hardware components, aiming to enhance the accuracy and real-time capabilities of our transcription system. Riya defines and monitors metrics to evaluate the quality of our real-time transcription, ensuring it meets the highest standards.
CE’24, e-mail: riyaa@bu.edu, phone number: 510-953-1814

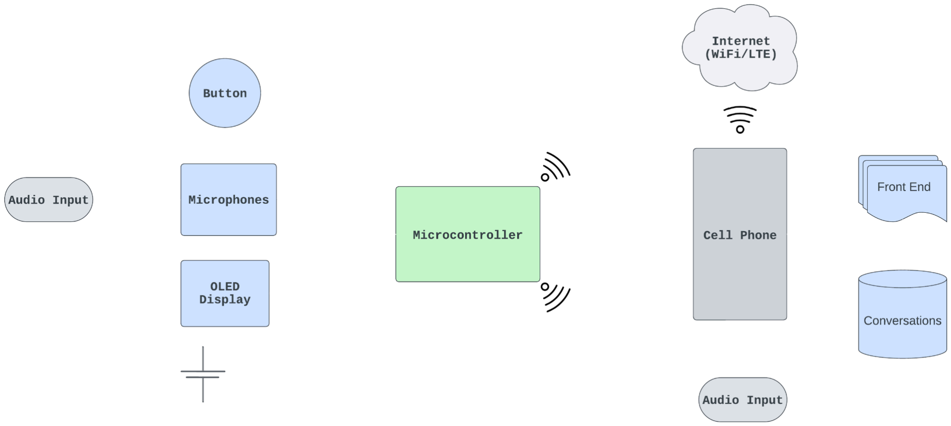
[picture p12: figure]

Fig. 2

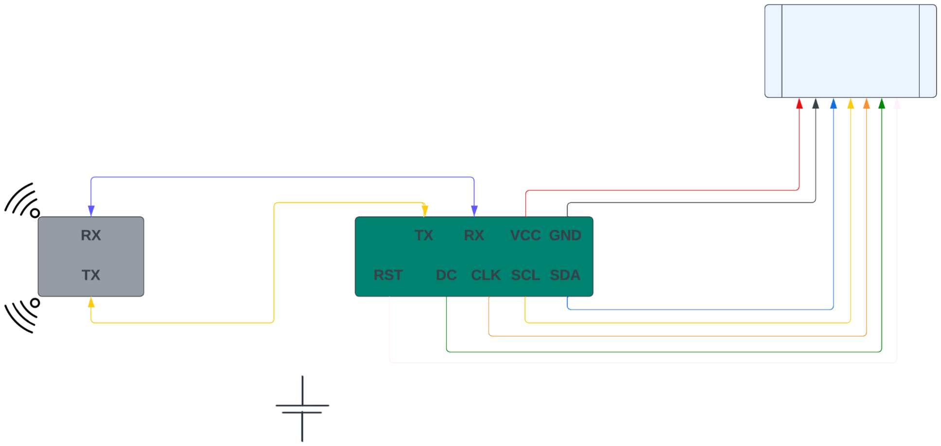
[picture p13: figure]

Fig. 3

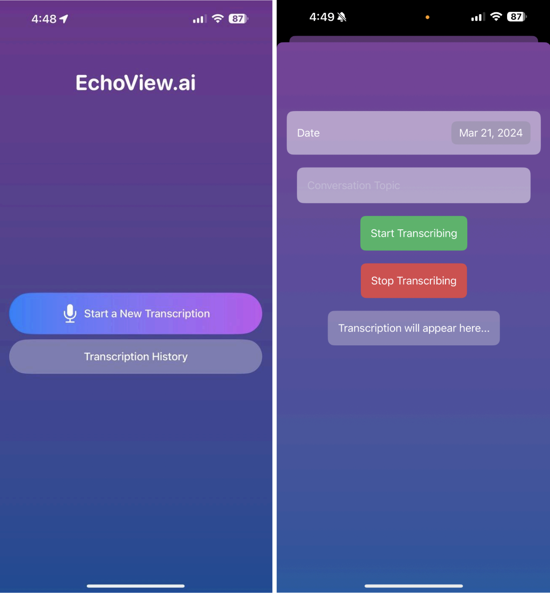
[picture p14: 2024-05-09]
images/swift_interface.png

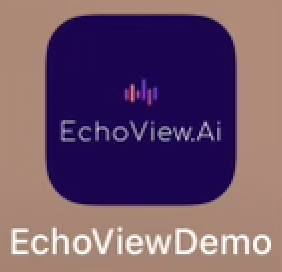
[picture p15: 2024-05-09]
images/swift_app.png

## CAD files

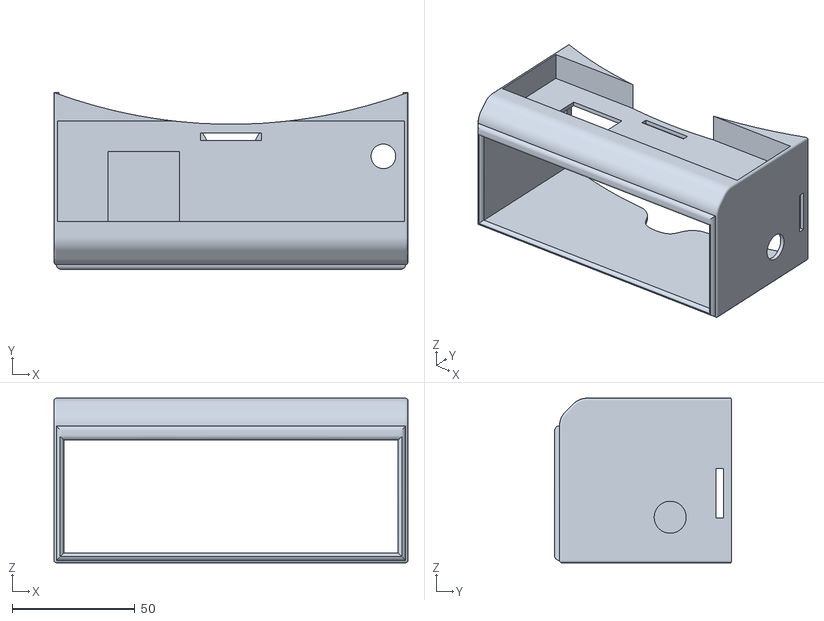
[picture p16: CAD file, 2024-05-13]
AR Glass Prototype.stl
144.0 x 72.0 x 67.0

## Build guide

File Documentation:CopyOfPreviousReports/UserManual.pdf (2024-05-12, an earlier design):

## Boston University Electrical & Computer Engineering

EC464 Senior Design Project

## User Manual

# EchoView.ai

by

Team 3
EchoView.AI

Team Members

Nicholas Hardy nckhrdy@bu.edu Riya Deokar riyaa@bu.edu
Jazmyn Walker jazmynw@bu.edu Marybel Boujaoude marybelb@bu.edu Hassan Hijazi hhijazi@bu.edu

User Manual Table of Contents

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
2.1. O

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
2.2. U

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
e. 6
2.3. P

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
2.4. I

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
3.1. O

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
1: N

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
3.2. O

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
2: A

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
3.3. S

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
4.1. H

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
4.2. M

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
4.3. S

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
Executive Summary

EchoView.AI
Team 03

The need for accessible, cost-effective, and immediate communication tools for the deaf and hard-of-hearing community is a critical issue. Current available technologies are costly, complex, and unable to be seamlessly integrated into daily life. Our solution is to introduce a revolutionary wearable device: glasses that provide real-time speech-to-text transcription. By integrating advanced technology into a discrete, everyday accessory, we will be reducing communication barriers faced by individuals who are deaf or hard of hearing. The final deliverable is a proof of concept equipped with an OLED display that will display transcribed text into the user’s field of vision, an ESP32-C3 for wireless communication, and two microphones for audio capture. Additionally, we will develop an iOS-compatible mobile application that enables the user to reference past conversations and customize the displayed text based on their preferences. Our technical approach leverages continuously improvable open-source speech recognition software, a practical optical design, and an efficient microcontroller. Our end product delivers a new way for deaf and hard-of-hearing individuals to communicate, cultivating a more inclusive world where every voice and word can be heard and understood.

### 1. Introduction

For the Deaf and hard-of-hearing community, seamless communication in a largely hearing world can be complicated and in some cases impossible. Despite continuous advancements in assistive technology, a significant gap persists in providing real-time, accessible, affordable, and convenient solutions. Approximately 1.5 billion individuals globally are affected by hearing loss in one or both ears, with an estimated 430 million people worldwide requiring rehabilitation for severe hearing loss. This number is expected to increase to 700 million people being affected by hearing loss by 2050 [1]. The effects of this communication gap are profound and have damaging consequences. Deaf and hard-of-hearing individuals often find themselves isolated from spoken conversations and missing out on everyday interactions. While current solutions exist, they are costly, lack immediate access, and are overall ill-suited for fast-paced real-world environments. Sign language interpreters can cost up to $150 per hour, not including additional travel costs, and often take prior planning to schedule [2]. Given these challenges, there is a clear and urgent need for an improved solution. The Global Assistive Technology Market was valued at 21.95 billion U.S. dollars in 2022 and is projected to reach a value of 31.22 billion U.S. dollars by 2030 [3]. More specifically, the domestic AR headsets and glasses market was valued at 2.4 billion U.S. dollars [4], and 31.12 billion dollars globally in 2023. AR and VR is a growing market with an expected growth of +366.91 percent by 2027, so entering this market with a more affordable option could accelerate the adoption of AR/VR and grant Echoview.ai a large share of the consumer market. Our proposed Augmented Reality (AR) glasses, with real-time speech-to-text capabilities and a mobile application, aim to address the communication barriers faced by the Deaf and hard-of-hearing community. Through a business-to-business (B2B) and business-to-consumer (B2C) model, we will introduce these Augmented Reality (AR) glasses to consumers who will benefit from improved accessibility at an affordable cost. Hospitals can communicate clearer between patients and staff, educational centers can integrate these glasses into their classrooms to promote an inclusive learning environment, and courtrooms can be sure that legal proceedings are accessible to all participants. Our device will enhance personal interactions, foster inclusivity, and provide a more cost-effective solution to existing assistive technologies.

### 2. System Overview and Installation

The EchoView.AI glasses system has evolved to utilize the ESP32-C3 microcontroller and the Siri framework for real-time speech-to-text transcription, enhancing accessibility for individuals who are deaf or hard of hearing. This system integrates Bluetooth microphones for audio capture, ensuring clear speech input in diverse environments. The ESP32-C3 microcontroller serves as the processing unit, executing the transcription model that converts speech into text. The text is then displayed on the OLED screen, strategically positioned for easy viewing without obstructing the user's field of vision. This setup ensures users who are deaf or hard of hearing can easily access spoken information.
Figure 2.1 illustrates the system workflow, where speech triggers the transcription module within the ESP32-C3 microcontroller. The text output is promptly displayed on the OLED screen, maintaining minimal latency and eliminating the need for an internet connection. Additionally, the system seamlessly connects to the EchoView.ai mobile app via Bluetooth, providing users with enhanced functionalities such as transcription management and device settings customization. Installation of the system entails setting up the ESP32-C3 microcontroller, pairing the Bluetooth microphones, and connecting the OLED display. Detailed instructions are provided to streamline the installation process, ensuring a user-friendly experience from setup to operation.
At the core of the system is the app, running a transcription model that converts speech captured by the microphones into text. These microphones are designed to pick up clear audio in various environments, ensuring reliable transcription. The text is then displayed on the OLED display, positioned to allow users to read without hindering their view.
Figure 2.1 shows the system workflow. Speech triggers the transcription module, where the ESP processes the audio and displays the resulting text almost instantaneously on the OLED screen. This process is designed to minimize latency and does not require an internet connection.
The system also connects to the EchoView.ai mobile app via Bluetooth, offering additional functionalities like transcription management and device settings customization.
Installation involves running the Swift and ESP code, connecting the microphones to Bluetooth and OLED display, and pairing the device with the mobile app. The process is streamlined for ease of setup, with detailed instructions provided for a hassle-free user experience.

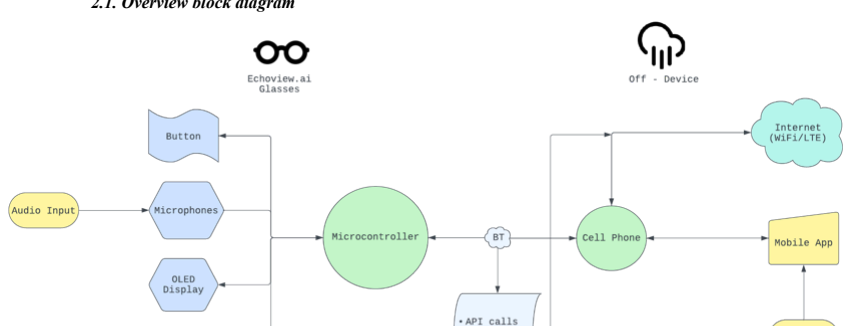
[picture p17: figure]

### 2.1. Overview block diagram

Figure 2.1: System Overview of the EchoView.AI Glasses
2.2. User interface.
The user interface for the EchoView.ai app is designed to be intuitive and user-friendly, focusing on seamless interaction between the user and the app's core functionalities. Activation of the app's features is straightforward: users can start the transcription process with a simple tap, eliminating the need for complex gestures or commands.
In addition to the primary app interface, the team has developed a companion iOS application that allows users to monitor their transcription history and view real-time transcription status updates. The app’s UI is crafted to automatically refresh and display the latest transcription data as soon as new speech is detected and processed, ensuring that users always have access to the most current information.

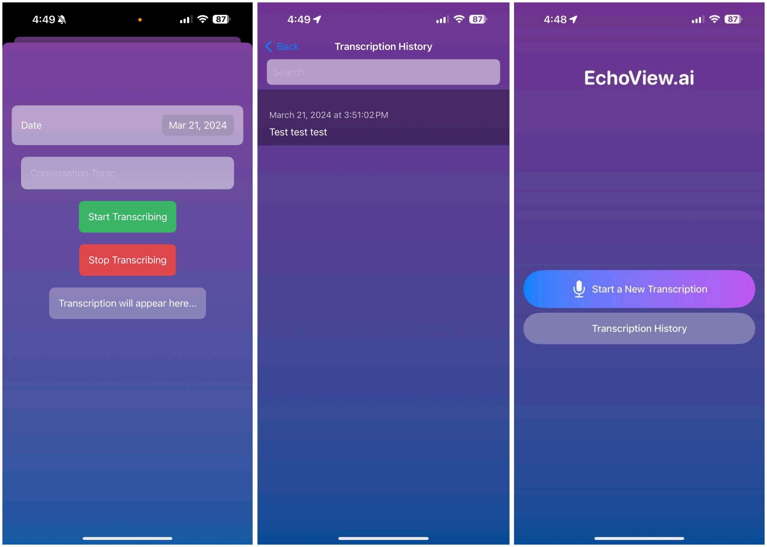
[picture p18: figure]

Figure 2.2: iOS Application UI

### 2.3. Physical description

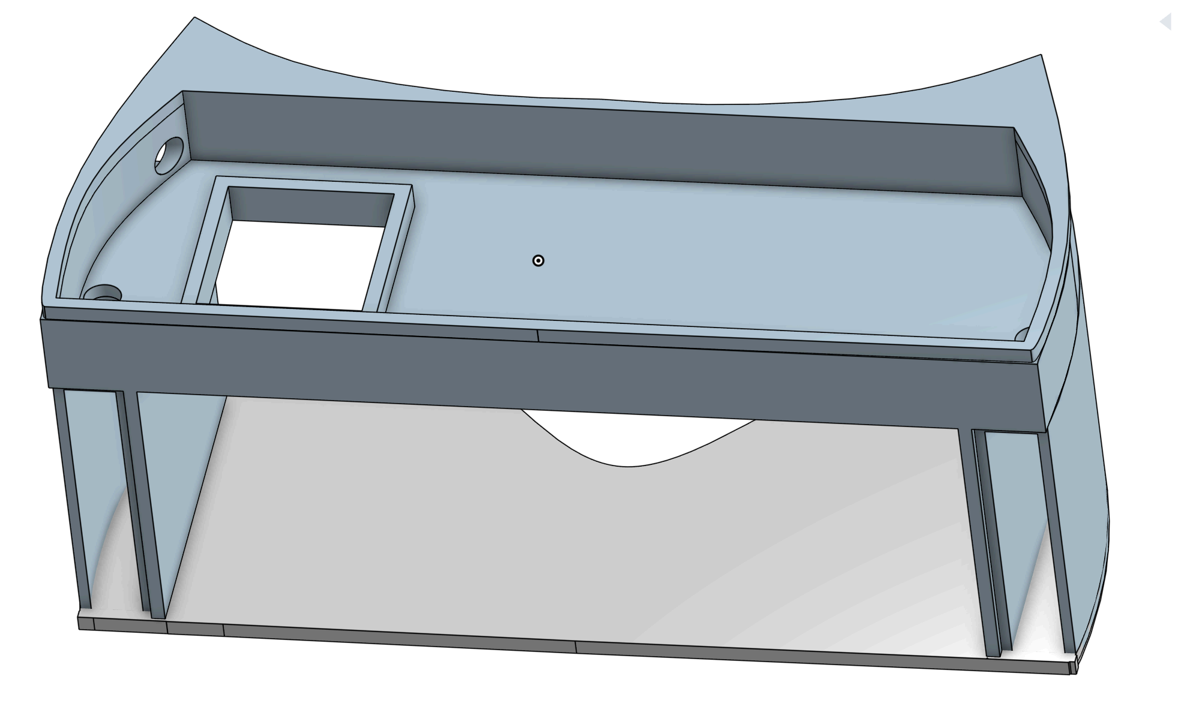
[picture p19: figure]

### 2.4. Installation, setup, and support

Installation: Each pair of EchoView.AI glasses is designed for immediate use, requiring minimal setup by the user. Upon purchase, users simply need to ensure the glasses are charged. The device is built to be intuitive and user-friendly, eliminating complex assembly processes. For optimal performance, the EchoView.AI glasses require a stable internet connection. It’s recommended to use them within a strong Wi-Fi signal range to maximize the functionality of their real-time speech-to-text transcription features.
Setup:
1. Download the EchoView.AI application from the App Store.
2. Create a user profile by registering with an email and password.
3. Pair the glasses with the app using a unique identification code provided with each pair.
4. Start experiencing real-time speech-to-text transcription.

Support: Recognizing the advanced nature of EchoView.AI glasses, we offer a comprehensive support system through an interactive iOS mobile application. This app is designed to enhance the user experience by offering clear visuals of transcribed speech, adjusting settings, and providing tips for optimal use. It also serves as a platform for troubleshooting and accessing customer support.

### 3. Operation of the Project

### 3.1. Operating Mode 1: Normal Operation

Activation
1. To activate EchoView.AI glasses for use, the wearer simply needs to turn them on. Notice: The current version is optimized for processing individual conversations in real-time. Overlapping or simultaneous speech may impact transcription accuracy.
2. The glasses are ready for immediate use once powered on, requiring no physical adjustments by the user.
iOS Application
The EchoView.AI iOS application serves as an interactive platform for users to
customize settings, view transcription history, and access support.
1. The app allows users to adjust font size, display speed, and other settings to personalize their viewing experience.
2. It displays transcription accuracy and a history of conversations for reference.
3. Users can access visual statistics on their usage patterns, including frequency and duration of use.
4. The app provides notifications for software updates, ensuring the glasses operate with the latest features and improvements.

### 3.2. Operating Mode 2: Abnormal Operations

Hardware errors
1. If the glasses fail to power on or respond, a simple reset by turning them off and on may resolve the issue.
2. Should sensors not activate properly, restarting the device and checking for obstructions or damage is advised.

### 3.3. Safety Issues

1. EchoView.AI glasses are designed for indoor use and may require specific care to maintain functionality, such as avoiding exposure to water or extreme temperatures.
2. Users should handle the glasses with care, avoiding rough treatment that could damage the delicate sensors and electronics.
3. When not in use, storing the glasses in a safe, dry place will help preserve their condition and ensure longevity.

### 4. Technical Background

### 4.1. Hardware Component

- MEMS Microphones
- MEMS (Microelectromechanical Systems) microphones are employed to capture ambient audio inputs. These microphones boast high sensitivity and low noise characteristics, ensuring accurate and reliable audio capture for subsequent processing.
- The MEMS microphones are strategically positioned to optimize audio capture from the user's environment, facilitating robust speech recognition and transcription capabilities.
- OLED Display
- An OLED (Organic Light Emitting Diode) display module is integrated into the EchoView.ai device to provide visual feedback to the user. The OLED display renders real-time transcribed text, enabling users to conveniently read incoming messages or conversation transcripts.
- The OLED display offers crisp, high-contrast visuals and consumes minimal power, making it well-suited for battery-operated wearable devices.
- Optical Combiner:
- The EchoView.ai device features an optical combiner, a critical component that overlays the OLED display output onto the user's field of vision. The optical combiner ensures that the transcribed text appears seamlessly integrated with the user's surroundings, enhancing readability and user experience.
- By employing advanced optics and precise alignment techniques, the optical combiner achieves optimal transparency and clarity, minimizing visual distractions while maximizing legibility.

### 4.3. Software Component

- Real-Time Speech-to-Text Transcription
- The iOS application developed with Swift 4 and Xcode features a speech-to-text transcription engine that converts spoken words captured by the device's microphones into text in real time. This feature enables deaf and hard-of-hearing users to easily understand spoken conversations by viewing the transcribed text on the device's display and storing conversations with generated titles.
- User Interface Design

- The frontend application has a user-friendly interface designed to enhance accessibility and usability. It incorporates clear and readable visuals, and intuitive navigation to ensure a seamless user experience.
- Large Language Model Whisper
- The C++ model facilitates accurate speech recognition and transcription, enhances natural language understanding, provides code generation assistance, and continuously improves over time. By leveraging its deep knowledge of C++ programming, it enables the EchoView.ai device to transcribe communication.
- Bluetooth Low Energy (BLE) Integration
- The EchoView.ai system utilizes BLE technology for wireless communication between the wearable device and the companion mobile application. BLE enables efficient data transfer while conserving energy, facilitating seamless interaction between the glasses and the user's smartphone. Implemented using BLE libraries, the code establishes services and characteristics for bidirectional communication, handles connection events, and enhances the device's usability and accessibility.
- MEMS code
- The microphone code facilitates audio capture for real-time speech recognition. It configures the MEMS microphones for optimal performance, capturing clear audio in various environments. Utilizing I2S communication protocol, the code reads audio samples from the microphones, processes them for transcription, and sends the data to the speech recognition module. Through efficient sampling and data processing techniques, the code ensures accurate transcription and seamless integration with the overall system.

### 5. Cost Breakdown

The cost breakdown approximates the costs to produce one EchoView.ai unit. It accounts for the hardware, software, and mechanical components of the EchoView.ai.

Item Description Cost/Unit Quantity Total Cost Hardware Components

Quantity | Item | Individual | Total
1 | Teensy 4.1 Development Board | $19.99 | $19.99
1 | Adafruit QT Py ESP32-C3 WiFi Dev Board with STEMMA QT 5405 | $31.99 | $31.99
2 | Adafruit I2S MEMS Microphone Breakout - SPH0645LM4H | $6.95 | $13.90
1 | Monochrome 0.96" 128x64 OLED Graphic Display - STEMMA QT | $23.99 | $23.99
1 | Sandisk 64GB | $19.99 | $19.99

Mechanical Components

1 | 3D Printing Filament | $11.00 | $11.00
| Total Cost | $175.85

Table 5.1. Production Cost Estimate for EchoView.ai

### 6. Engineering Standards

1. Use of Approved Components and Protocols: The project utilizes standard components like the Teensy 4.1 microcontroller and the ESP32-C3 module, which are likely designed in accordance with industry standards for electronic devices. The use of BLE (Bluetooth Low Energy) for communication is in line with the Bluetooth standard IEEE 802.15, ensuring interoperability and efficient power usage.
2. Safety and Efficiency: By focusing on a lightweight design (<300 grams) and ensuring the device can withstand drops from 1.5 meters, the project likely aligns with standards related to the safety and durability of wearable devices. The emphasis on power efficiency, aiming for a battery life of at least 4 hours, also indicates an effort to comply with standards for energy-efficient electronic devices.
3. Software and Documentation: The development of an iOS-compatible mobile application and the use of open-source speech recognition software suggest adherence to software development and documentation standards. Proper software documentation is crucial for maintainability, scalability, and usability, aligning with the guidelines mentioned in the presentation.
4. Component Specifications: The project's attention to using components according to manufacturer specifications, such as the OLED display and microphones suitable for speech recognition, aligns with the standard compliance practices outlined in the PowerPoint. This ensures the reliability and optimal performance of each component within the system.

Appendix A - Specifications

Requirements | Value, range, tolerance, units
ESP32-C3 Dimensions | 40mm x 27mm
Power Supply | Single 5V power supply with a minimum output of 2A for ESP32-C3
Bluetooth Microphone Compatibility | Compatible with Bluetooth microphones with a range of 50 meters (164 feet)
OLED Display | Size: 1.3 inches; Resolution: 128x64 pixels
Latency Transcription | No latency progressed from less than 4 second latency to realtime audio capture to display on OLED
Battery Life | Minimum battery life of 6 hours for wearable device functionality
Wearability | Comfortable fit for users with easy readability of OLED display

Appendix B - Team information

Team 3, or Team EchoView.ai, consists of Riya Deokar, Hassan Hijazi, Nicholas Hardy, Jazmyn Walker, and Marybel Boujaoude. All team members are majoring in Computer Engineering while Riya Deokar is additionally concentrating in Machine Learning and Nicholas Hardy and Marybel Boujaoude are concentrating in Technology Innovation.

Hassan Hijazi is a senior computer engineering student with a passion for creating innovative solutions using emerging technologies. He has a keen interest in machine learning and its applications in assistive technology.

Nicholas Hardy is a senior computer engineering student with a focus on embedded systems and IoT devices. He enjoys tackling complex hardware challenges and optimizing system performance.

Riya Deokar is a senior computer engineering student with a background in software development and human-computer interaction. She is dedicated to designing user-friendly interfaces that enhance accessibility and usability.

Marybel Boujaoude is a senior computer engineering student with a strong foundation in system design and integration. She is committed to ensuring the seamless operation of all hardware and software components.

Jazmyn Walker is a senior computer engineering student with expertise in wireless communication and signal processing. She is passionate about developing reliable and efficient wireless systems for real-world applications.

Together, Team EchoView.AI is driven by a shared goal of creating a transformative assistive technology solution that improves the lives of individuals who are deaf or hard of hearing. Through collaboration, innovation, and perseverance, we are committed to delivering a product that makes a meaningful difference in the world.

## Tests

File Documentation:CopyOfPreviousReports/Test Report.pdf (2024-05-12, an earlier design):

# Memo

To: | Professor Pisano
From: | Hassan Hijazi, Nicholas Hardy, Riya Deokar, Marybel Boujaoude, Jazmyn Walker
Team: | EchoView.AI
Date: | 11/14/23

Subject: First Prototype Testing Report

### 1.0 Required Materials

Hardware:
- OLED Display
- ESP32-C3 Module
o Power Supply: 3.0V to 3.6V

Software:
- Espressif IoT Development Framework (ESP-IDF)
- Xcode
o Swift Programming Language

### 2.0 Setup

Our testing setup involves a structured plan focusing on both hardware integration and software development. The hardware module consists of the OLED display, which will show the converted speech-to-text, and the ESP32-C3, which is necessary for its Wi-Fi and Bluetooth capabilities. Regarding the software aspect, we will be using Xcode and the Swift programming language to develop an iOS compatible mobile application, tailored for user interaction and data visualization. The app will include a feature where the phone’s microphone will listen and take in audio input and then convert it into written text directly on the screen. This is a backup option for our user in scenarios where the device might run out of battery and lose power. After initial testing, we will focus on combining both aspects of the hardware and software pieces to seamlessly work together and create a cohesive system for the user.

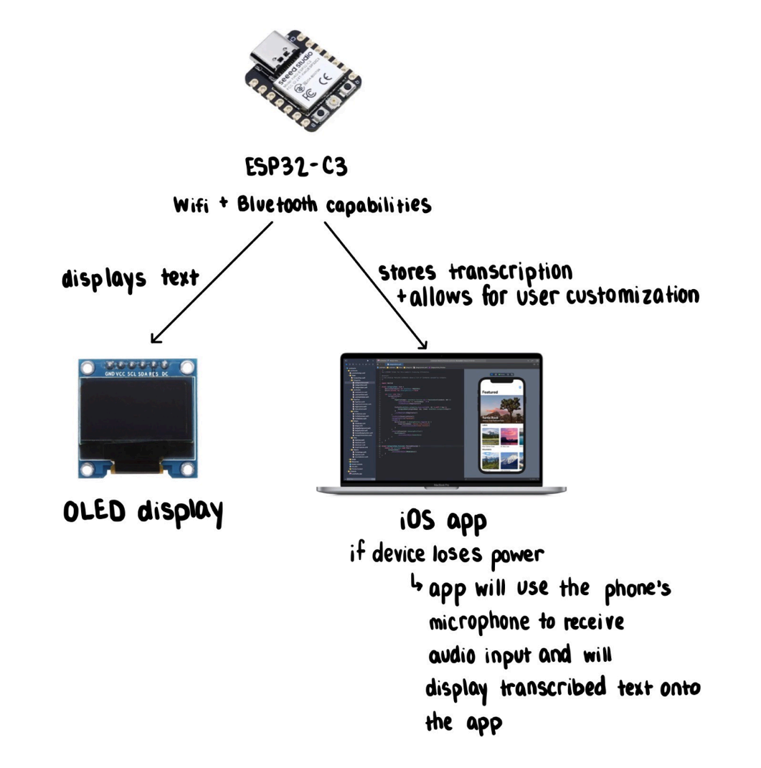
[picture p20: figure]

Figure 1: Illustration of Setup and Process Flow

### 2.1 Pre-testing Setup Procedure

ESP-32-C3 side:
1. Install ESP-IDF and Python 3 using HomeBrew
2. Set up the tools used by ESP-IDF (compiler, debugger, Python packages, etc.)
3. Set up the environment variables
a. Run in terminal: .$HOME/esp/esp-idf/export.sh

Xcode side:
1. Download the Xcode app

### 2.2 Testing Procedure

1. Test the OLED display by running the code onto the device and ensuring the text displays properly
2. Check the audio capture and processing capabilities on the iOS mobile application through Xcode on the iPhone simulator

### 2.3 Measurable Criteria

The criteria for successful running and output is as follows:
I. The app successfully takes in audio input and accurately displays the text onto the screen in real-time with minimal latency
II. The OLED displays text that is easily readable

### 3.0 iOS Mobile Application Testing Results

To test the accuracy of the iOS mobile application, we created a short paragraph of sixty-six words and read it out loud as the app was working. We then reviewed the transcribed text and compared it to the written text. We found how many words were incorrect to determine the accuracy of our algorithm.

Test paragraph:
“Testing a speech-to-text system requires a well-structured paragraph that includes a variety of sounds and word combinations. This test paragraph includes common and uncommon words, challenging the system's ability to accurately transcribe speech. It contains plosives, fricatives, and nasals, ensuring a comprehensive assessment of the system's capabilities. The paragraph should be read aloud at a natural pace, with clear enunciation. The time is 4:30 pm.”

While performing the test, we kept in mind a few possibilities that might lead to error for example:

- Clarity and Accuracy
- Question: Will the app be able to accurately transcribe clear speech?
- Testing Procedure: One person read the test paragraph out loud in a clear, natural tone
- Result: The app was able to accurately transcribe spoken words
- Background Noise Handling
- Question: Is the app able to accurately transcribe speech in noisy environments?
- Testing Procedure: One person read the paragraph while in a noisy lab environment with other people talking
- Result: The system was able to filter out background noise and still accurately transcribed the speech
- Speech Variability
- Question: Can the system handle different speech patterns?
- Testing Procedure: We had multiple different people with different accents, speech speeds, and tones read the paragraph
- Result: The system was accurately able to transcribe various speech patterns

Table of Results:

### 4.0 Discussion of test results

The average accuracy of our app according to our table of test results is 96%. This indicates high performance and proves that our app is able to accurately transcribe spoken words in different scenarios. Our lowest percent accuracy was 90% while our highest was 100%. This demonstrates the consistency that our app has as it is a small range of recorded percentages. While the results are predominantly positive, there is still room for improvement as there are slight variations in the accuracy. Overall, the system gives high accuracy results which seems ready for real-world deployment and further testing, however continuous monitoring and user feedback will be essential for improvement.

### 5.0 OLED Testing Results

We initially had the OLED fully running successfully with the ESP32-C3, where it was able to display text onto the screen, however during in-lab testing we received an error saying “OLED configuration failed”. After further examination of the device, we realized the OLED was cracked and therefore needed to be replaced. Once this issue was resolved and a new replacement OLED was obtained, we were able to successfully run the code onto the device and display written text.

# of Correct Words | Percentage Accuracy

65 | 98%
62 | 93%
66 | 100%
61 | 92%
60 | 90%
64 | 96%
65 | 98%
63 | 95%
64 | 96%
65 | 98%
Result | 96%

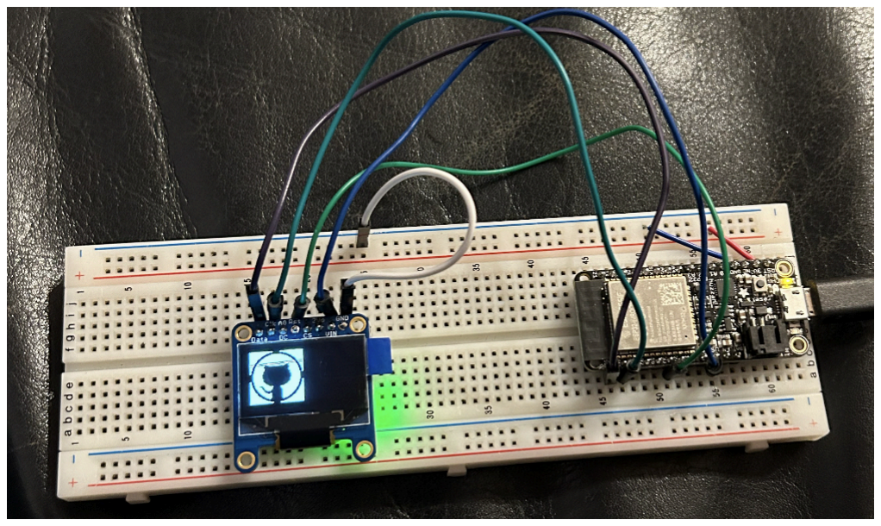
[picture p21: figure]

Figure 2: OLED display running with ESP32

### 6.0 Conclusion

Overall, the first prototype testing of our EchoView.AI project has shown immense progress and promising results. In our iOS mobile application testing, we achieved an average accuracy rate of 96%. This high level of performance shows the reliability and success of our speech-to-text algorithm among various environments and speech patterns. The challenges we faced with the OLED display, specifically with the cracked screen, were valuable learning experiences as they highlighted the importance of durability in our hardware choices, especially for a wearable device intended for daily use. As we move forward, our focus will be on refining the system based on the insights gained from this initial testing phase.

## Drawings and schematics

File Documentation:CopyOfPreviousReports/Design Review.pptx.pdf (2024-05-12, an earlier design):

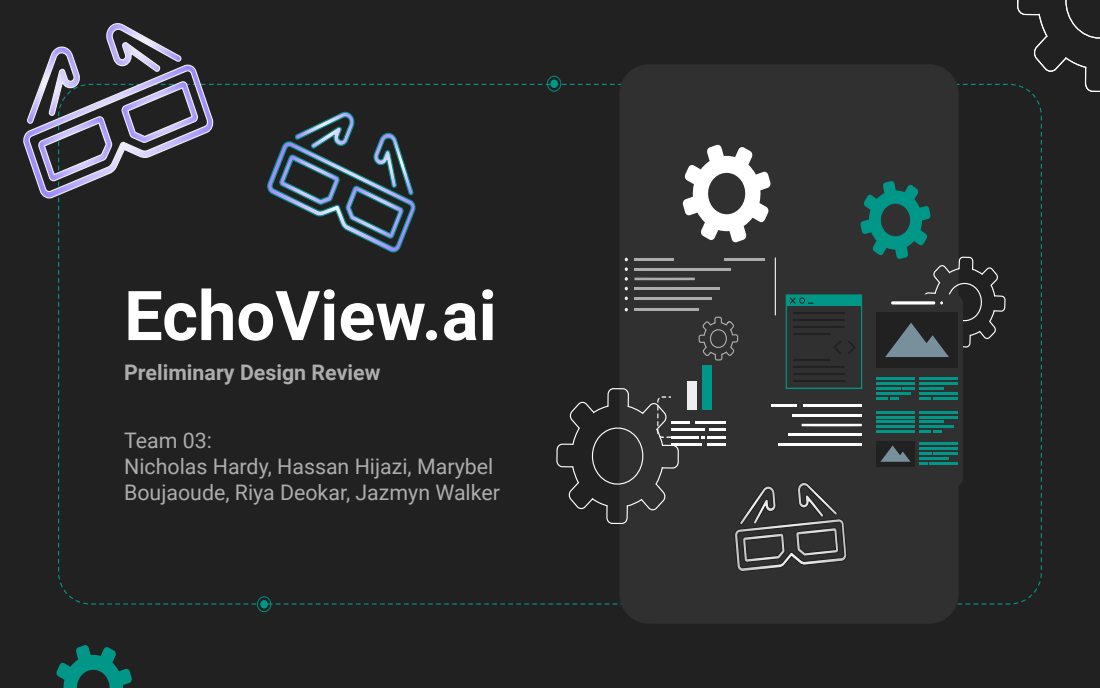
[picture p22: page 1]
EchoView.ai

Preliminary Design Review

Team 03:
Nicholas Hardy, Hassan Hijazi, Marybel
Boujaoude, Riya Deokar, Jazmyn Walker

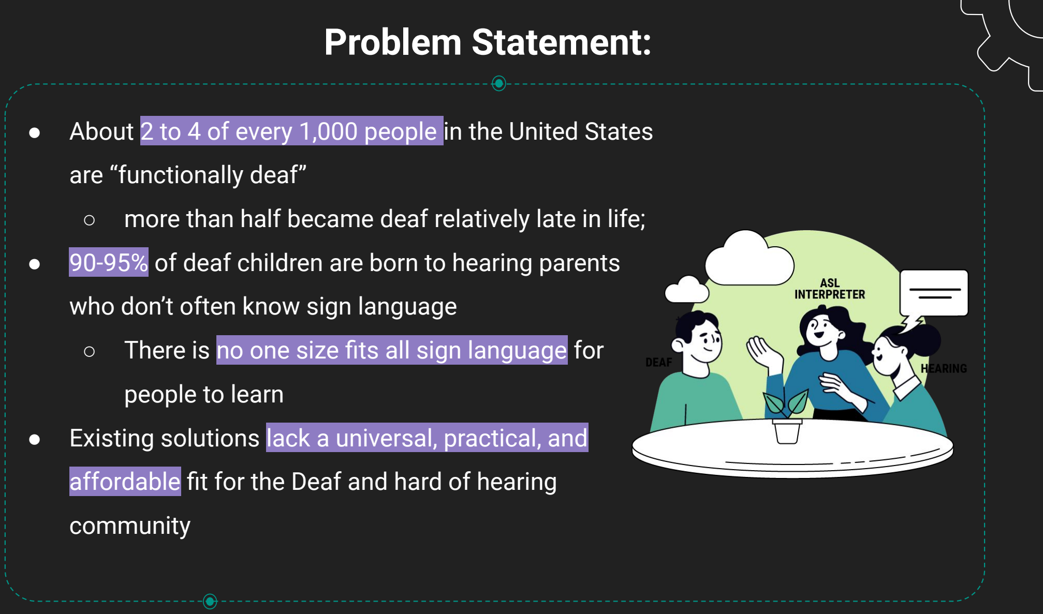
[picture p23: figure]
Problem Statement:; are “functionally deaf”; who don’t often know sign language; people to learn; community

- About 2 to 4 of every 1,000 people in the United States
- more than half became deaf relatively late in life;
- 90-95% of deaf children are born to hearing parents
- There is no one size fits all sign language for
- Existing solutions lack a universal, practical, and

affordable fit for the Deaf and hard of hearing

## Solution:

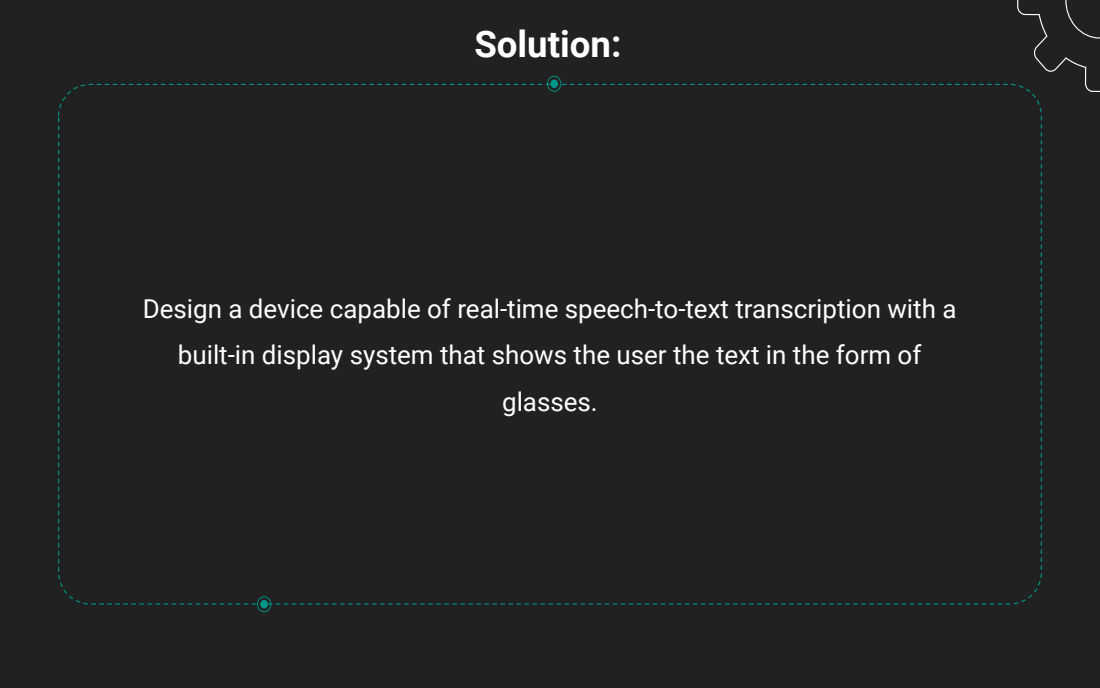
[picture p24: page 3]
glasses.

Design a device capable of real-time speech-to-text transcription with a
built-in display system that shows the user the text in the form of

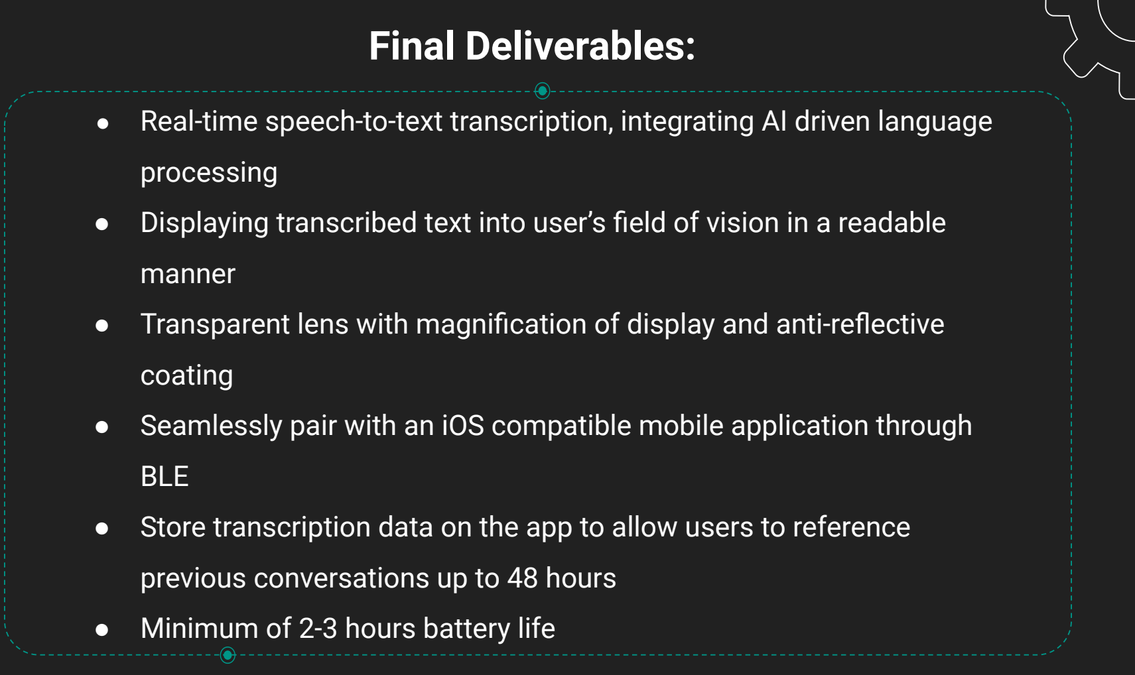
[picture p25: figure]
Final Deliverables:; processing; manner; coating; BLE; previous conversations up to 48 hours; ● Minimum of 2-3 hours battery life

- Real-time speech-to-text transcription, integrating AI driven language
- Displaying transcribed text into user’s field of vision in a readable
- Transparent lens with magnification of display and anti-reflective
- Seamlessly pair with an iOS compatible mobile application through
- Store transcription data on the app to allow users to reference

## System Block Diagram:

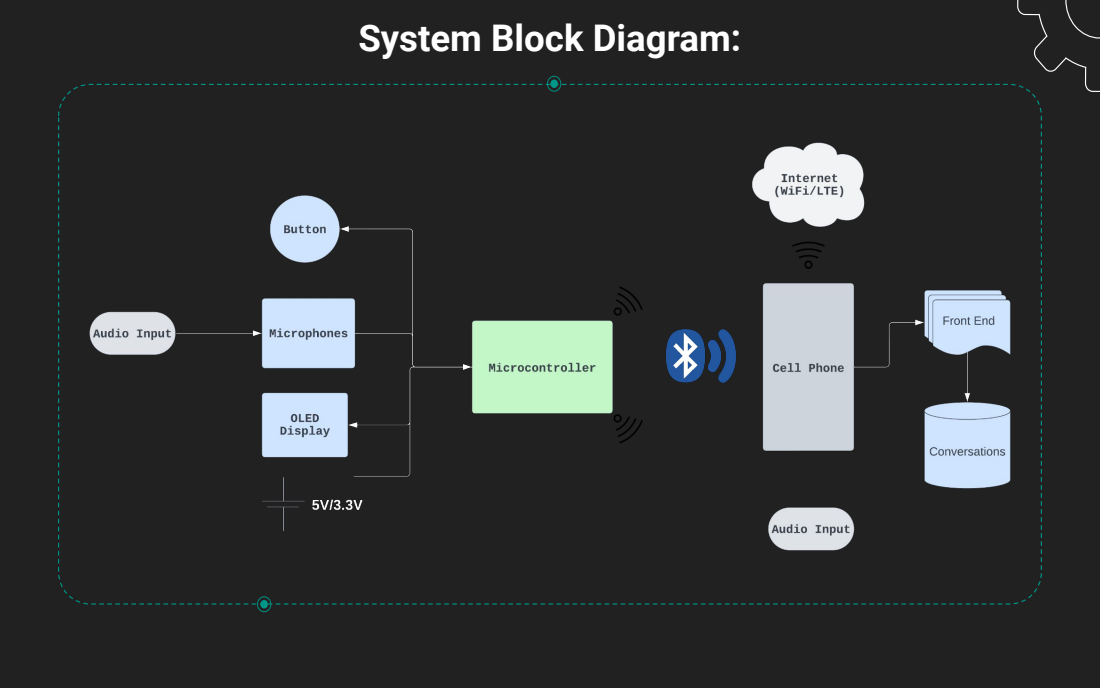
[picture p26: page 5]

## Hardware:

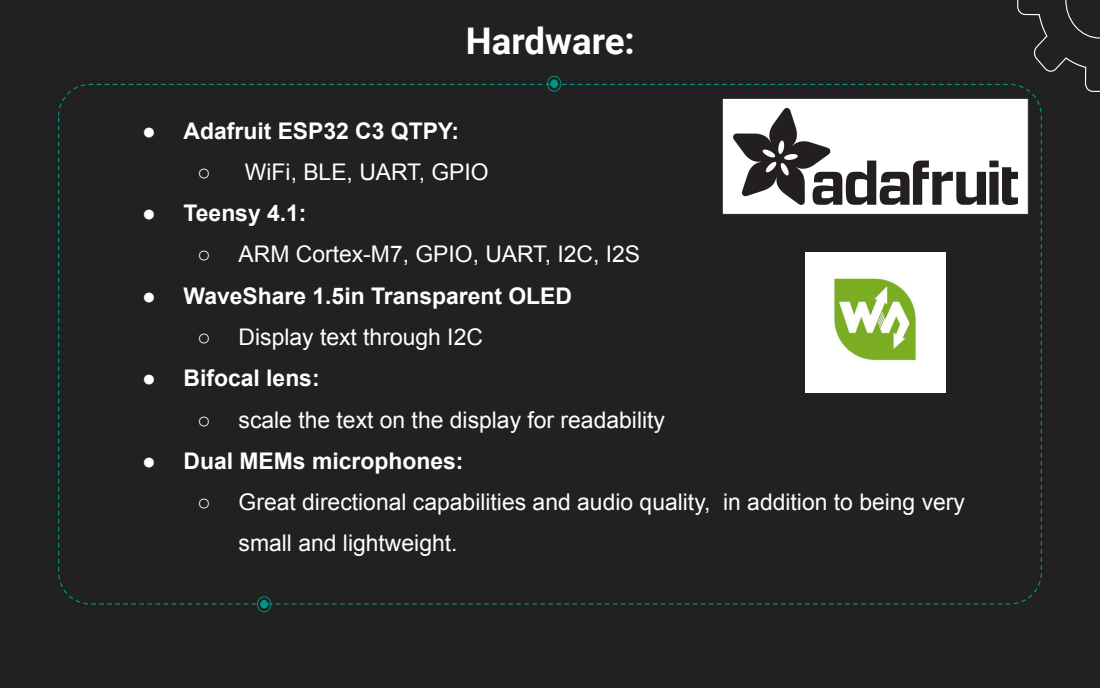
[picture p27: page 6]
● Adafruit ESP32 C3 QTPY:; ● Teensy 4.1:; ● Bifocal lens:

○ WiFi, BLE, UART, GPIO

○ ARM Cortex-M7, GPIO, UART, I2C, I2S

● WaveShare 1.5in Transparent OLED

○ Display text through I2C

○ scale the text on the display for readability

● Dual MEMs microphones:

○ Great directional capabilities and audio quality, in addition to being very

small and lightweight.

## Glasses Hardware:

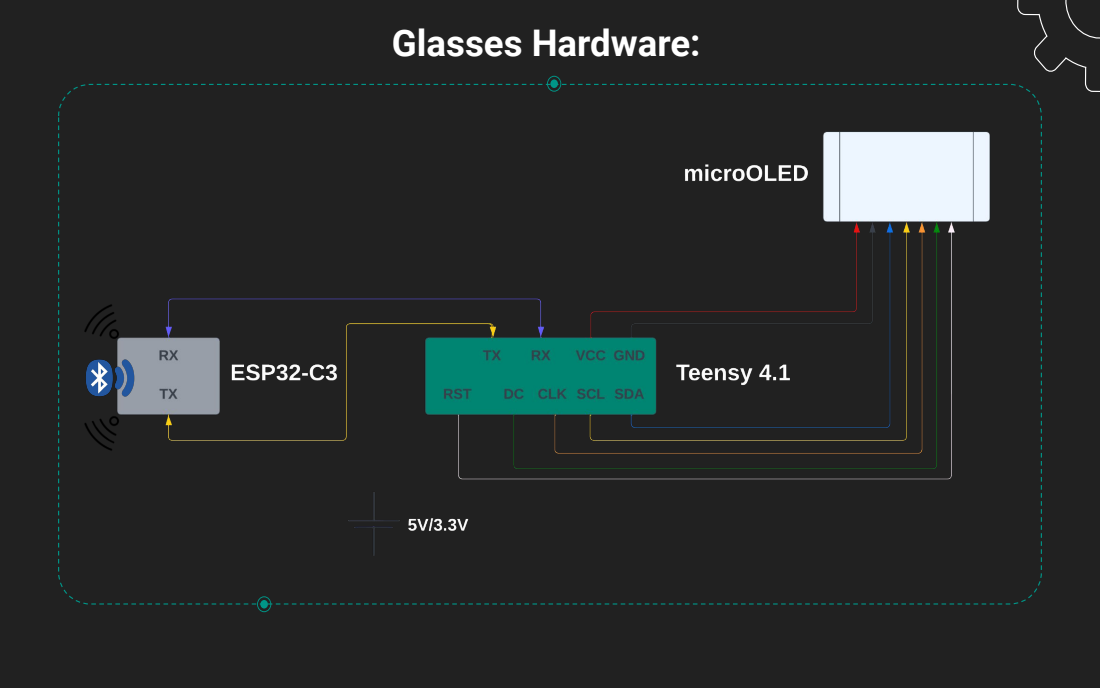
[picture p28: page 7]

## Glasses Firmware:

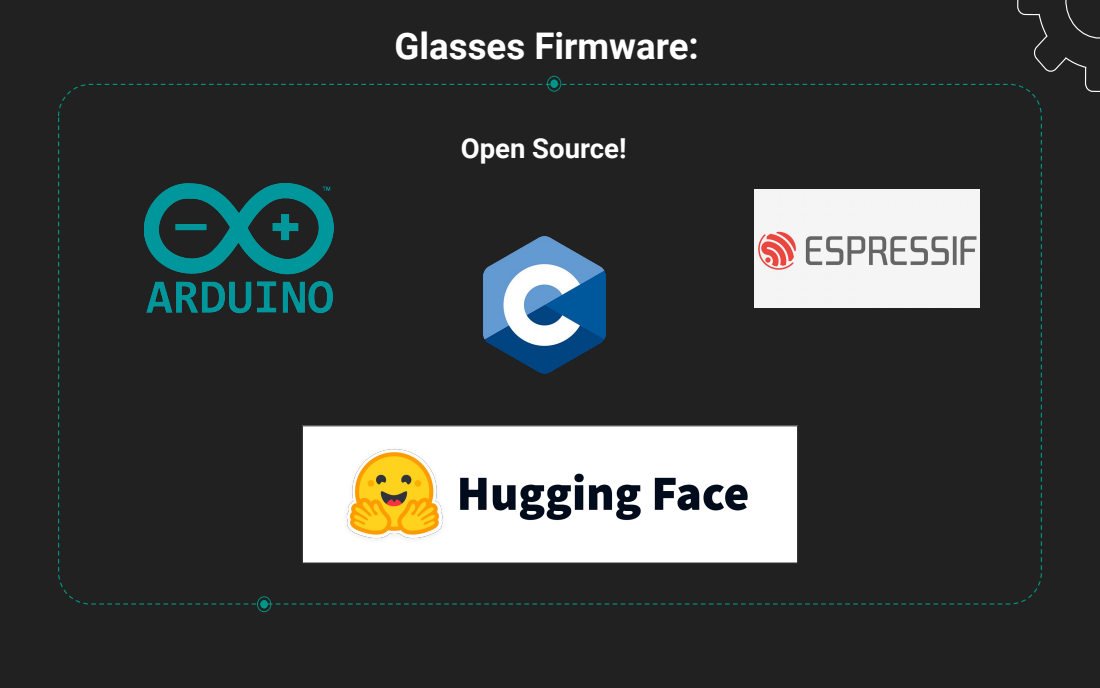
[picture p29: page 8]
Open Source!

## Software: Front End

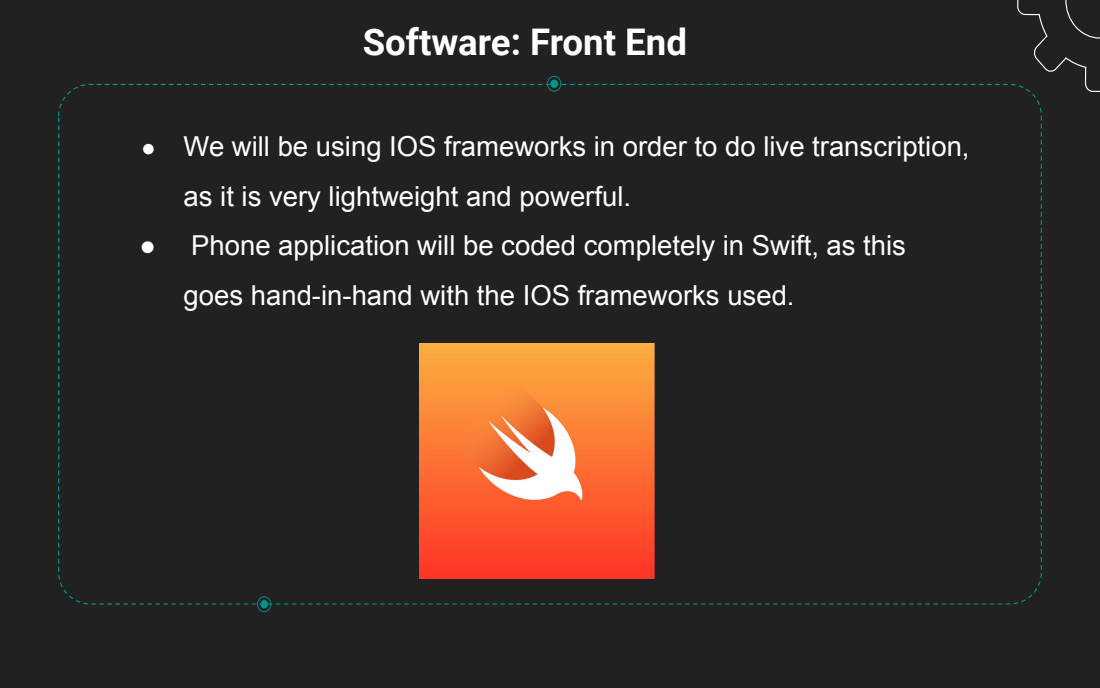
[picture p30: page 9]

● We will be using IOS frameworks in order to do live transcription,

as it is very lightweight and powerful.

● Phone application will be coded completely in Swift, as this

goes hand-in-hand with the IOS frameworks used.

## User Flow

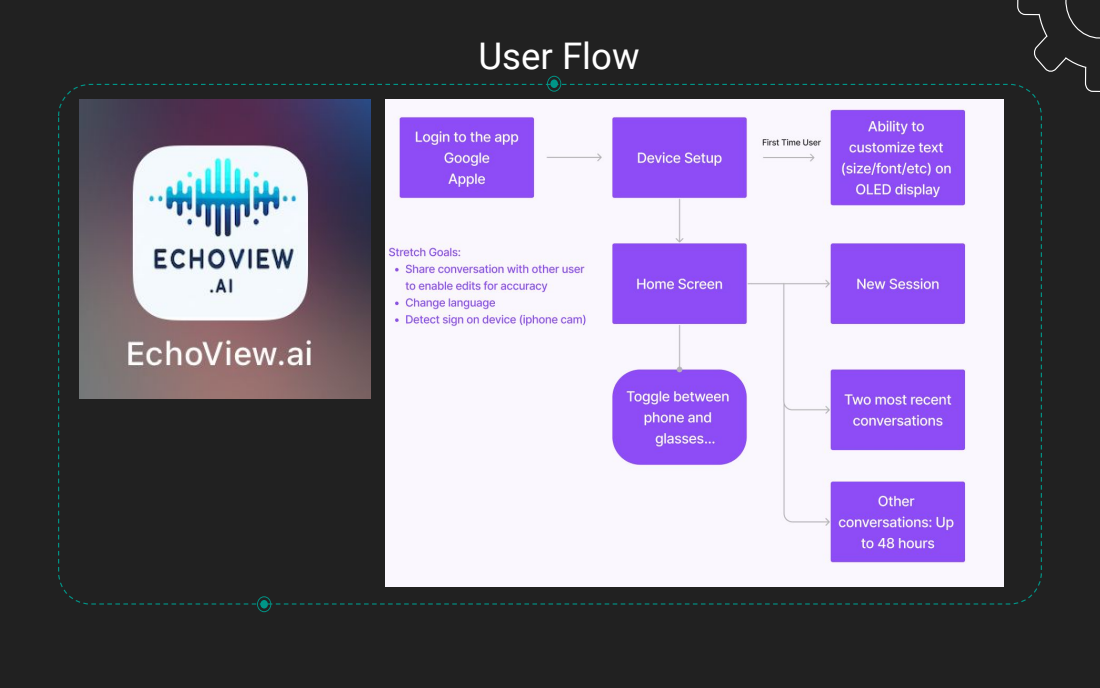
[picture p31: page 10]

## Software: Embedded Systems

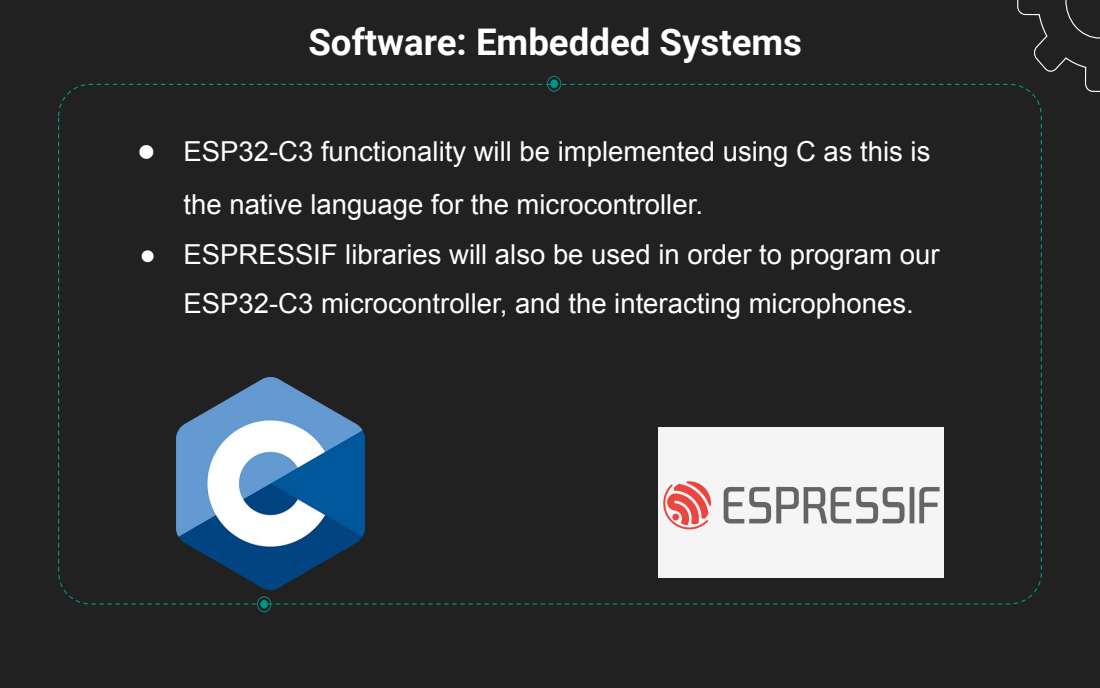
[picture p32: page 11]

● ESP32-C3 functionality will be implemented using C as this is

the native language for the microcontroller.

● ESPRESSIF libraries will also be used in order to program our

ESP32-C3 microcontroller, and the interacting microphones.

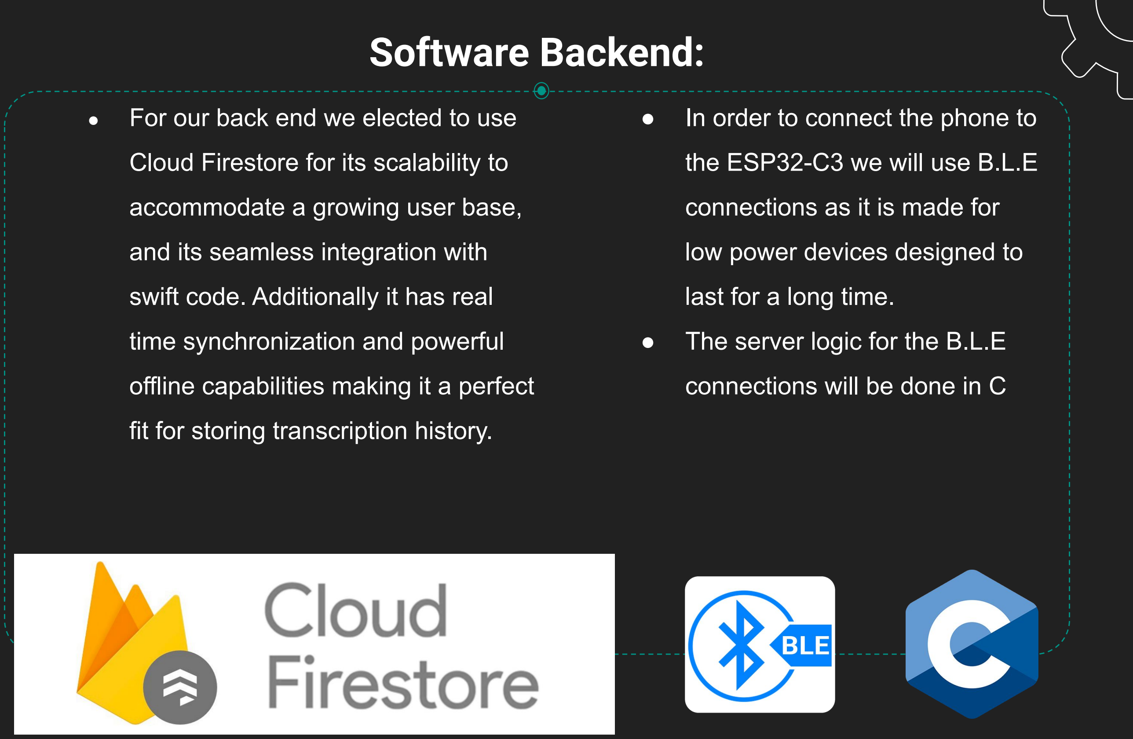
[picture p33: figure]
Software Backend:; ● For our back end we elected to use; Cloud Firestore for its scalability to; accommodate a growing user base,; and its seamless integration with; swift code. Additionally it has real; time synchronization and powerful; fit for storing transcription history.; ● In order to connect the phone to; the ESP32-C3 we will use B.L.E; connections as it is made for; low power devices designed to; last for a long time.; ● The server logic for the B.L.E; connections will be done in C

offline capabilities making it a perfect

Testing:; proper nouns.; crowded room.

- Tests for live transcription was done using a 100 word paragraph

that contained numbers, homophones, uncommon words, and

- Results are based on the accuracy of the live transcription app,

in outputting the correct transcription out of 100.

- We ran the same test in a silent room, and in a consistently loud

environment of 70 decibels which is the average noise of a

## Testing:


Testing Round: | Quiet Room: | Noisy Room (~70 Decibels)

Average: | 99.4% | 95.4

## Gantt Chart:


https://docs.google.com/spreadsheets/d/1p4gv2rEuFxZHB539TNdgT8H865Gg2BvP1Qfjbd2tv70/edit#gid=0

Future Progress; enhanced transcription and translation accuracy.; reduction in noisy environments.; ● Minimum 2-3 hours of battery life.; exploring multi-language translation.

- Testing magnification lens for optimal readability.
- Continued development of AI-driven language processing for
- Testing of directional microphones to ensure effective noise
- Touch on stretch goals such as ability to respond to transcribed

conversations, gesture recognition for hands-free control and

Comments/Questions?; Thank You

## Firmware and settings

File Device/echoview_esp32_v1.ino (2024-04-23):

#include <SPI.h>
#include <Wire.h>
#include <Adafruit_GFX.h>
#include <Adafruit_SSD1306.h>
#include <BLEDevice.h>
#include <BLEServer.h>
#include <BLEUtils.h>
#include <BLE2902.h>

#define SCREEN_WIDTH 128 // OLED display width, in pixels
#define SCREEN_HEIGHT 64 // OLED display height, in pixels
#define OLED_RESET -1 // Reset pin # (or -1 if sharing Arduino reset pin)
#define SCREEN_ADDRESS 0x3D ///< See datasheet for Address; 0x3D for 128x64, 0x3C for 128x32
Adafruit_SSD1306 display(SCREEN_WIDTH, SCREEN_HEIGHT, &Wire, OLED_RESET);

#define SERVICE_UUID "ABC0FCC1-2FC3-44B7-94A8-A08D0A0A5079"
#define CHARACTERISTIC_INPUT_UUID "A1AB2C55-7914-4140-B85B-879C5E252FE5"
#define CHARACTERISTIC_OUTPUT_UUID "A43954A4-A6CC-455C-825C-499190CE7DB0"

BLECharacteristic *pOutputCharacteristic;

#define MAX_CHARS_PER_LINE 16 // Adjust based on your display and font size
#define MAX_LINES 4
String lines[MAX_LINES]; // Array to hold lines of text
int currentLine = 0; // Index of the current line being used

void addText(String text) {
    // Check if current line + new text exceeds max characters per line
    if (lines[currentLine].length() + text.length() > MAX_CHARS_PER_LINE) {
        // Check if we need to scroll up
        if (currentLine >= MAX_LINES - 1) {
            // Scroll lines up
            for (int i = 0; i < MAX_LINES - 1; i++) {
                lines[i] = lines[i + 1];
            }
            lines[MAX_LINES - 1] = text;
        } else {
            // Move to next line
            lines[++currentLine] = text;
        }
    } else {
        // Append text to current line
        if (!lines[currentLine].isEmpty()) {
            lines[currentLine] += " ";
        }
        lines[currentLine] += text;
    }

    // Redraw the display
    display.clearDisplay();
    display.setTextSize(1); // Normal 1:1 pixel scale
    display.setTextColor(SSD1306_WHITE); // Draw white text
    for (int i = 0; i <= currentLine; i++) {
        display.setCursor(0, i * 8); // Move down 8 pixels per line
        display.println(lines[i]);
    }
    display.display(); // Show the display buffer on the screen
}

class MyServerCallbacks: public BLEServerCallbacks {
    void onConnect(BLEServer* pServer) override {
        Serial.println("Client Connected");
    }

    void onDisconnect(BLEServer* pServer) override {
        Serial.println("Client Disconnected");
        BLEDevice::startAdvertising(); // Ensure we're still discoverable after disconnect.
    }
};

class MyCallbacks: public BLECharacteristicCallbacks {
    void onWrite(BLECharacteristic *pCharacteristic) override {
        std::string value = pCharacteristic->getValue();

        if (!value.empty()) {
            Serial.print("Received Value: ");
            String text = ""; // Create an empty string to hold incoming text
            for (auto &it : value) {
                Serial.print(it);
                text += it; // Append received characters to the string
            }
            Serial.println();

            // Update OLED display with received text
            addText(text); // Use the addText function to handle display updates

            // Optionally, echo the value back to the client as a confirmation
            pOutputCharacteristic->setValue(value);
            pOutputCharacteristic->notify();
        }
    }
};

void setup() {
    Serial.begin(115200);

    // Initialize OLED display
    if (!display.begin(SSD1306_SWITCHCAPVCC, SCREEN_ADDRESS)) {
        Serial.println(F("SSD1306 allocation failed"));
        for (;;); // Don't proceed, loop forever
    }
    display.display(); // Show initial display buffer (splash screen or blank)
    delay(2000); // Pause for 2 seconds
    display.clearDisplay(); // Clear the buffer

    display.setRotation(0);

    // Initialize BLE
    BLEDevice::init("ESP32-C3-QT-PY");
    BLEServer *pServer = BLEDevice::createServer();
    pServer->setCallbacks(new MyServerCallbacks());

    BLEService *pService = pServer->createService(SERVICE_UUID);

    BLECharacteristic *pInputCharacteristic = pService->createCharacteristic(
                                                CHARACTERISTIC_INPUT_UUID,
                                                BLECharacteristic::PROPERTY_WRITE | BLECharacteristic::PROPERTY_WRITE_NR);
    pInputCharacteristic->setCallbacks(new MyCallbacks());

    pOutputCharacteristic = pService->createCharacteristic(
                                                CHARACTERISTIC_OUTPUT_UUID,
                                                BLECharacteristic::PROPERTY_NOTIFY);
    pOutputCharacteristic->addDescriptor(new BLE2902());

    pService->start();
    BLEAdvertising *pAdvertising = BLEDevice::getAdvertising();
    pAdvertising->addServiceUUID(SERVICE_UUID);
    pAdvertising->setScanResponse(true);
    pAdvertising->setMinPreferred(0x06);
    BLEDevice::startAdvertising();

    Serial.println("Waiting for a client connection to notify...");
}

void loop() {
    // No operation needed in the loop for this example.
    delay(1000);
}

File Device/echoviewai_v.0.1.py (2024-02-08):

import board
import digitalio
from PIL import Image, ImageDraw, ImageFont
import adafruit_ssd1306
import subprocess
import textwrap

# Create the I2C interface.
i2c = board.I2C()

# Create the SSD1306 OLED class.
oled = adafruit_ssd1306.SSD1306_I2C(128, 64, i2c, addr=0x3D)

# Clear the display.
oled.fill(0)
oled.show()

# Create blank image for drawing.
width = oled.width
height = oled.height
image = Image.new('1', (width, height))

# Get drawing object to draw on image.
draw = ImageDraw.Draw(image)

# Define constants for text display.
padding = -2
top = padding
x = 0

# Load default font.
font = ImageFont.load_default()

# Calculate the width and height of a character drawn with the font.
char_width, char_height = font.getsize('A')

# Define the update_display function to include text wrapping.
def update_display(text):
    # Clear the display image.
    draw.rectangle((0, 0, width, height), outline=0, fill=0)
    
    # Wrap the text and draw it on the display.
    for i, line in enumerate(textwrap.wrap(text, width // char_width)):
        # Stop if there's no more room on the display.
        if i * char_height >= height:
            break
        # Draw the text line by line.
        draw.text((x, top + i * char_height), line, font=font, fill=255)
    
    # Display the image.
    oled.image(image)
    oled.show()
# Command to execute the stream program
command = "make -j stream && ./stream -m models/ggml-tiny.en.bin --step 4000 --length 8000 -c 0 -t 4 -ac 1024"

# Start the subprocess and redirect stdout and stderr
process = subprocess.Popen(command, shell=True, stdout=subprocess.PIPE, stderr=subprocess.STDOUT, text=True)

# Loop to read the subprocess output line by line
while True:
    line = process.stdout.readline()
    if not line:
        break  # If no more output, break the loop
    print(line)  # For debugging: print the line to the console
    update_display(line.strip())  # Update the display with the current line

# Clean up
process.stdout.close()
process.wait()
